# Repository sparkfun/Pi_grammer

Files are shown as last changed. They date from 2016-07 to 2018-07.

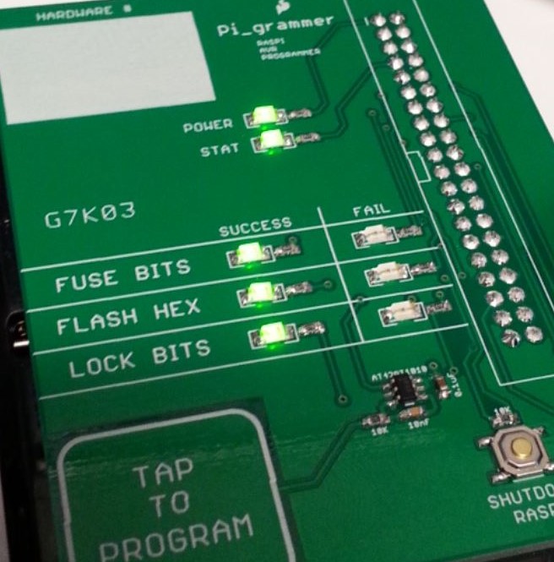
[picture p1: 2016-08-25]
Documentation_ example_&_pics/verify.jpg

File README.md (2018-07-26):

SparkFun Pi AVR Programmer HAT
========================================

SparkFun Raspberry Pi Stand-Alone Programmer w/ the Pi-Grammer Hat

[*SparkFun Pi AVR Programmer HAT (DEV-14747)*](https://www.sparkfun.com/products/14747)

A shield for Raspberry Pi 2, used for programming AVR ICs. Includes capsense pad to engage, 2x3 ISP header for connectivity and status LEDs.

Documentation
--------------
* **[Hookup Guide](https://learn.sparkfun.com/tutorials/pi-avr-programmer-hat-hookup-guide)** - Basic hookup guide for the Pi AVR Programmer Hat.
* **[Raspberry Pi Stand-Alone Programmer](https://learn.sparkfun.com/tutorials/raspberry-pi-stand-alone-programmer)** - more information about the prototype can be found in the article.

Additional Notes
--------------
This project originated from Adafruits tutorial here:

https://learn.adafruit.com/program-an-avr-or-arduino-using-raspberry-pi-gpio-pins/overview

This shield makes it a bit easier to program AVRs with a headless Raspberry Pi.

This repo also contains some other useful files:

* **RCLOCAL** - calls /home/pi/test.py and ensure that this python module will run automatically at boot up (useful when running headless)

* **AVRDUDE config file** - sets the GPIO used for programming (in avrdude) to work with the shield design. It's located at the very end of this file.

* **test.py** - the python module that is auto called during bootup. This also listens to the capsense IC and engages programming when p ressed.

**Note:** test.py called pi_program.sh to actually begin programming.

**Note:** test.py also checks for MEDIA drives plugged into the USB ports of the Raspi. If there is a HEX file on the MEDIA drive (any name, it just has to have the ".hex" extension) it will copy it in and use that for programming.

KEYWORDS: RASPI PROGRAMMER

Troubleshooting Tips
--------------

1) USB port issues. If you are having trouble with com port enumeration. That is, you are plugging in something like an FTDI serial basic, and the Raspi will not recognize it. This may be fixed by using one of SparkFun Cerberus USB hub cables. We found that after plugging in 20+ FTDI basics into a pi, then it stops recognizing the devices. But if you use a hub (like the cerberus) inbetween the pi USB and the serial bridge IC, then it always pops up as "/dev/ttyUSB0" for 1000s of boards in a row. Wahoo!

SparkFun Cerberus USB Cable

[SparkFun Cerberus USB Cable](https://www.sparkfun.com/products/12016)

License Information
-------------------

This product is _**open source**_! 

Please review the LICENSE.md file for license information. 

If you have any questions or concerns on licensing, please contact techsupport@sparkfun.com.

Distributed as-is; no warranty is given.

- Your friends at SparkFun.

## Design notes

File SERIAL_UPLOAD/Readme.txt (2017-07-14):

Note, you must install arduino for the serial upload to work. The latest Pigrammer image should have this done already, but if needed, here is the command:

sudo apt-get install arduino

////////////////
Note, you will need to plug in an ethernet cable to your pi 2, to connect to the internet. I found that I needed to open a browser a couple times for it to actually connect to the internet (which you need for the apt-get to work).

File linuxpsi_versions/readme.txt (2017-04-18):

Note, you must follow some setup instructions on an SFE tutorial to get SPI setup correctly. 

You can find that here:

https://learn.sparkfun.com/tutorials/raspberry-pi-spi-and-i2c-tutorial#spi-on-pi

SPI on Pi
Configuration

The SPI peripheral is not turned on by default. To enable it, do the following.

Run sudo raspi-config.
Use the down arrow to select 9 Advanced Options
Arrow down to A6 SPI.
Select yes when it asks you to enable SPI,
Also select yes when it asks about automatically loading the kernel module.
Use the right arrow to select the <Finish> button.
Select yes when it asks to reboot.

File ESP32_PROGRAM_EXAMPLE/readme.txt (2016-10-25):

Note, the espressif folder and all it's contents must live in the /home/pi folder for the pi_program.sh example to call the correct python moldule esptool.py

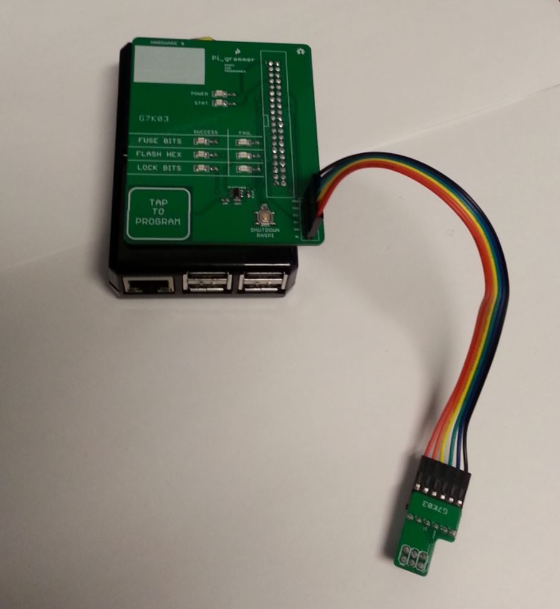
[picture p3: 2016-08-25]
Documentation_ example_&_pics/Pi_grammer_with_adapter.jpg

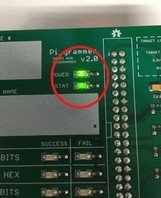
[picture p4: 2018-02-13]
Documentation_ example_&_pics/V20_pics/stat.jpg

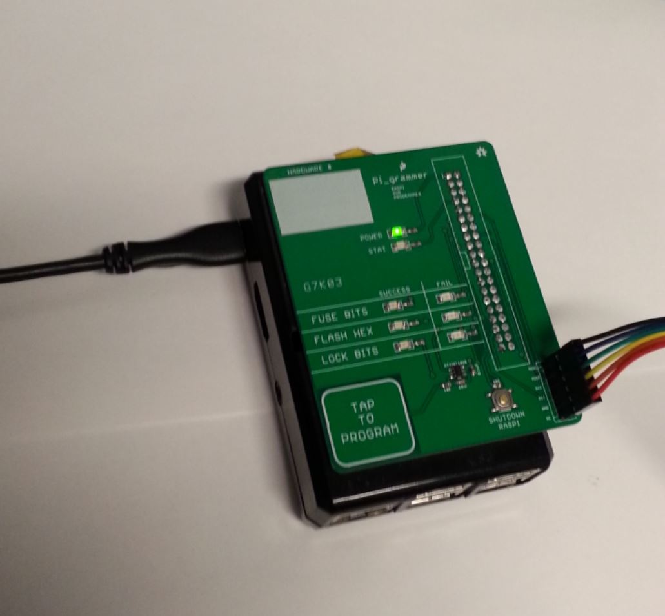
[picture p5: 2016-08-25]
Documentation_ example_&_pics/power.jpg

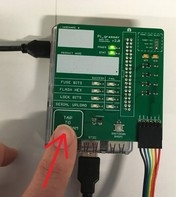
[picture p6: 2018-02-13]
Documentation_ example_&_pics/V20_pics/tap.jpg

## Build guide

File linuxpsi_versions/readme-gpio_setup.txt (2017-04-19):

Note, you will also need to insall the gpio control stuff for the hard reset to work.

Read more at tutorial here:

https://learn.sparkfun.com/tutorials/raspberry-gpio#c-wiringpi-setup

Or you can simply run these commands: (also note that you'll need to be connected to a hard line to the internet for this to pull the necessary git clone). And don't forget the darn "sudo" - oh how I loath permissions.

sudo mkdir code
sudo ch code

pi@raspberrypi ~/code $ sudo git clone git://git.drogon.net/wiringPi
pi@raspberrypi ~/code $ sudo cd wiringPi
pi@raspberrypi ~/code/wiringPi $ sudo git pull origin
pi@raspberrypi pi@raspberrypi ~/code/wiringPi/wiringPi $ sudo ./build

test gpio control like so:

pi@raspberrypi ~/code $ gpio -g mode 18 output
pi@raspberrypi ~/code $ gpio -g write 18 1
pi@raspberrypi ~/code $ gpio -g write 18 0

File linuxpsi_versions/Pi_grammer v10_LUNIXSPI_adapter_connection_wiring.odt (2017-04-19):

Pi_grammer v10

SPI adapter wiring instructions

Pete Lewis

4/19/2017

For use with “linuxspi” programmer in avrdude.

Note, I originally designed the Pi_grammer to use GPIO pins to “bitbang” SPI. This is slower than using the built in SPI hardware pins on the raspi. And is problematic when programming large hex files.

The Pi_grammer hardware should be revised to use the true SPI hardware pins (and include a logic level converter to allow for 5V targets), but for now, we can wire up our adapters and only use it on 3.3V boards.

Here are the SPI hardware pins:

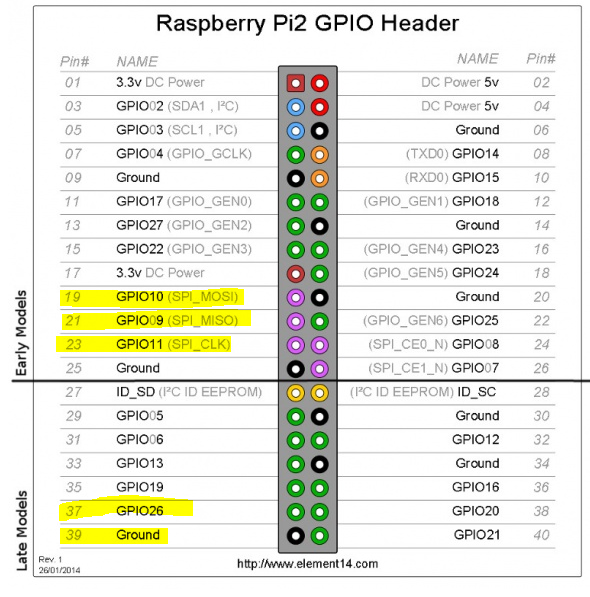
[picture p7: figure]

This is what it looks like on my soldered board. The MOSI/MISO/CLK actually line up nicely with the 1x6 adapter order.

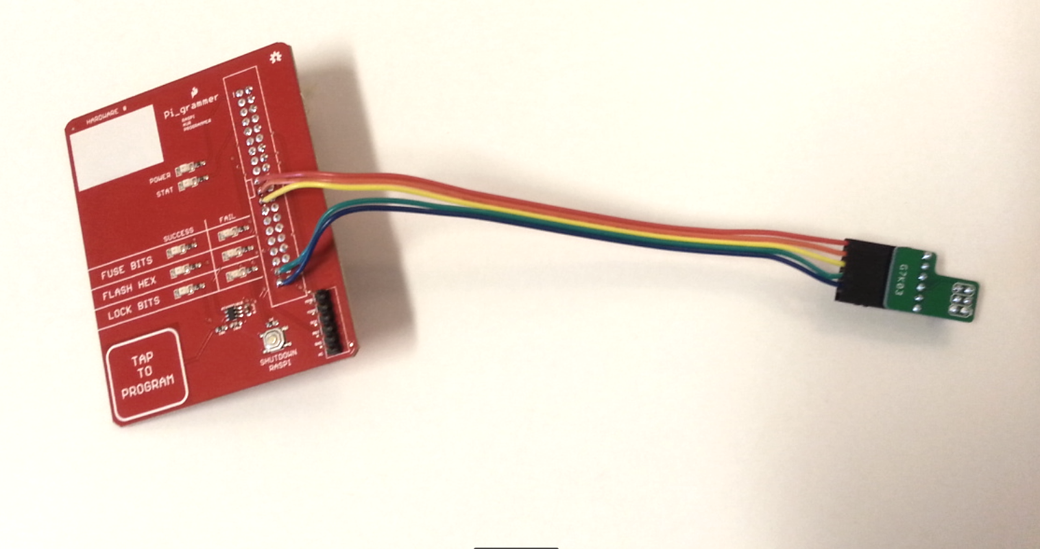
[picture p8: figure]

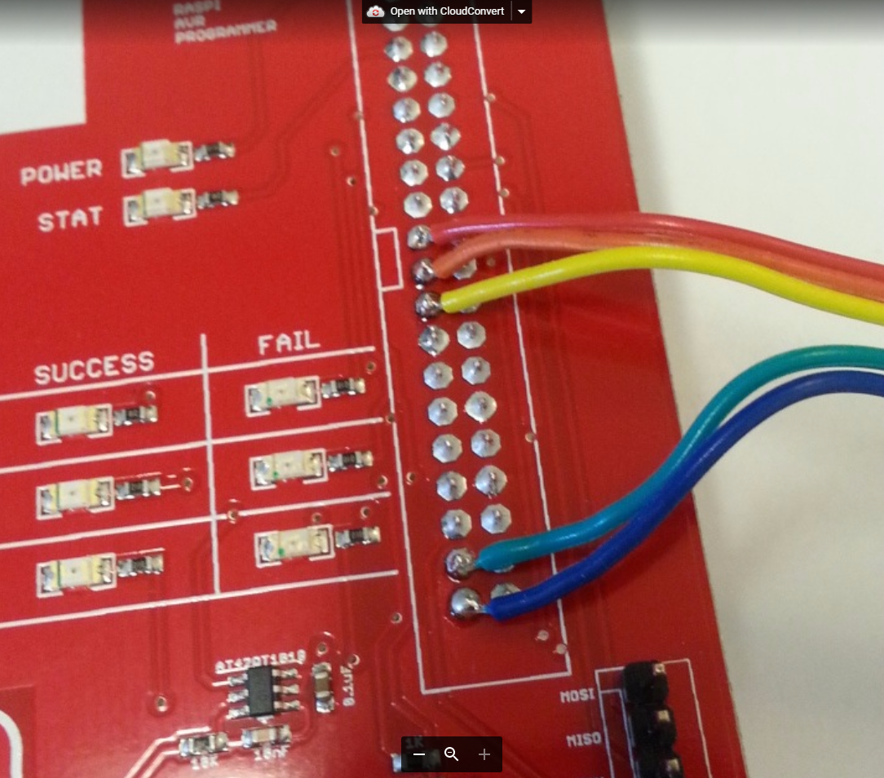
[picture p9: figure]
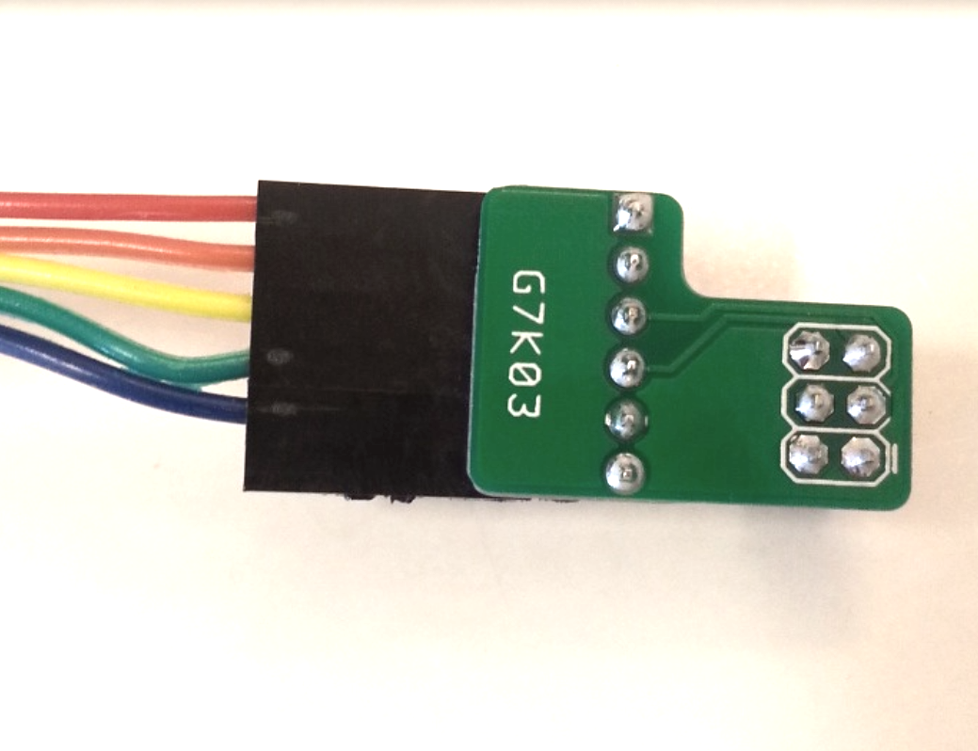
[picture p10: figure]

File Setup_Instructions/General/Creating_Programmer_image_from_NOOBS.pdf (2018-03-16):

Creating a Pi_grammer Image from NOOBs PL 3/16/2018

This guide will show how to take a fresh NOOBs card, and make some slight tweaks to get it setup as a Pi_grammer..

1. Copy a few files to “\home\pi” directory: test.py, pi_program.sh, avrdude_gpio.conf, your_firmware.hex.

Note, it’s a good idea to open up permissions on all of these files to avoid access errors in debug. To do this navigate to \home\pi, then type use the command “sudo chmod 777 test.py pi_program.sh your_firmware.hex”

Also note, the avrdude_gpio.conf file is pretty similar to the standard CONF file, although it has two additional programmers setup at the bottom of the file. This is added to the end:

# Linux GPIO configuration for avrdude.

# Change the lines below to the GPIO pins connected to the AVR.

programmer
id = "pi_1";
desc = "Use the Linux sysfs interface to bitbang GPIO lines"; type = "linuxgpio";
reset = 19;
sck = 24;
mosi = 23;
miso = 18;
;

programmer
id = "linuxspi";
desc = "Use the Linux SPI device in /dev/spidev*"; type = "linuxspi";
reset = 26;
;
2. Enable SPI hardware tutorial here: https://learn.sparkfun.com/tutorials/raspberry-pi-spi-and-i2c-tutorial#spi-on-pi
3. Replace the standard RC.LOCAL file with the one from the repo. It is located here: “\etc”

4. Install avrdude. A single command will do this: “sudo apt-get install avrdude” but you can read more about it here adafruits gpio tutorial (https://learn.adafruit.com/program-an-avr-or-arduino-using-raspberry-pi-gpio-pins/installation)
Note, there is no need to create the modified config file for gpio if you intend to use linuxspi.

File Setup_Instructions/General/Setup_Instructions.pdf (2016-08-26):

Pi_Grammer Setup Instructions PL 8/26/2016

This guide will show how to setup a Pi_Grammer for production.

1. Grab a Raspi 2, a micro SD card (with generic Pi_grammer image pre-programmed) Pi_grammer Shield, 1x6 cable and adapter.
2. Create a bash file with proper fuse/ext/lock bits.
- Note, this can be done on your “usual” computer to avoid having to setup the Pi with a screen/mouse/keyboard each setup.
- Please start with the example “pi_program.sh” file that lives in the repo.
- Most of the time, you should only need to adjust the fuse/ext/lock bits. These are variables at the top of the bash file, for ease of editing.

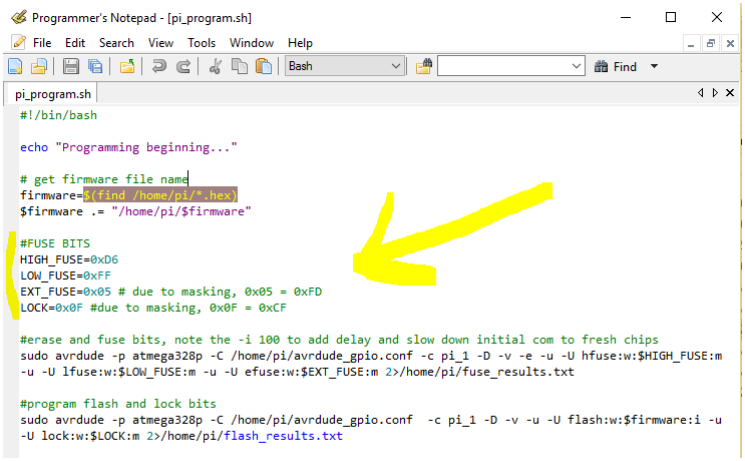
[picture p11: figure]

- Note, AVRDUDE will not let you write to “unused” bits. This effects how we write to the EXT and LOCK bits:
- If you want to write the value “0xFD” to the EXT bit (which is a common value we write on a lot of 328 based arduino products), then use the value “0x05” in AVRDUDE.

- The 3 bits on the right are the only ones we care about.
- “0xFD” = 1111 1101
- “0x05” = 0000 0101
- If you want to write the usual “0xCF” to LOCK, then write 0x0F” in AVRDUDE.
- The 4 bits on the right are the only ones we care about.
- “0xCF” = 1100 1111
- “0x0F” = 0000 1111
3. Go get the hex file from the product folder.
4. Copy the hex file and bash file onto your thumb drive.

Note, the hex file can be named anything (and so should be left the same as it was – for traceability). The bash file must be named exactly “pi_program.sh”. These should be the only two files on the thumb drive.

5. Plug in the uSD card (with generic image) into your Pi.
6. Power up your Pi with a microB USB cable (either a computer hub or wall wort).
7. Wait for blinking stat LED. This indicates that bootup is complete and the python script is running.
8. Take your prepared thumb drive (with hex and bash files) from your windows machine, and plug in your thumb drive into USB on the Pi.
9. Verify the circular LED sequence happens twice.
- One for hex file.
- Second for bash file.

- This verifies that the python script recognized the “media” device, found a “.hex” and a “pi_program.sh” file on it., and copied it to the local folder successfully.

10.Remove thumb drive.
11. Shutdown the Pi.
- Press and hold the “SHUTDOWN” button.
- All LEDs begin blinking.
- When blinking stops, that means it has fully shut down.
- Unplug power.

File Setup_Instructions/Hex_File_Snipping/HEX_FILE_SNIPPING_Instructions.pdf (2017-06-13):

HEX File Snipping Instructions PL 6/13/2017

Summary:
This guide will show how to remove unnecessary “blank” space in a hex file. This is useful when you want to keep the hex file as small as possible.

Why would you need this:
When a product has a bootloader and some “sketch code”, we will read back the entire flash space and use this as our “combined” HEX file for programming in production. Often times, this also includes a lot of blank space in the HEX file (between the sketch code and the bootloader).
1. Read the entire flash space of your IC. ATMEGA328s should come in at 91KB.
2. Open HEX file in a text editor. Here, I use Programmer Notepad.
3. Scroll up and down in the HEX file and notice the three sections:

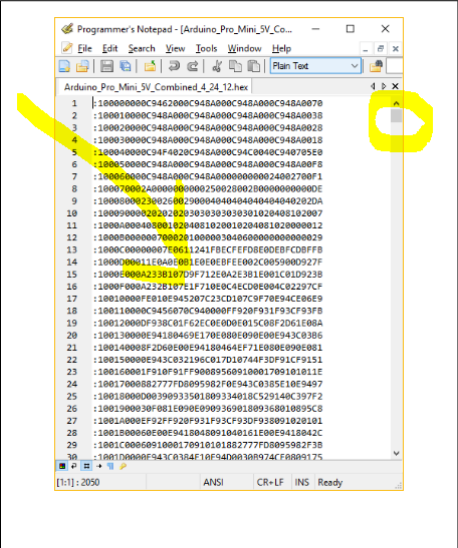
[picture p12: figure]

I. “good stuff” up top. (Sketch code).

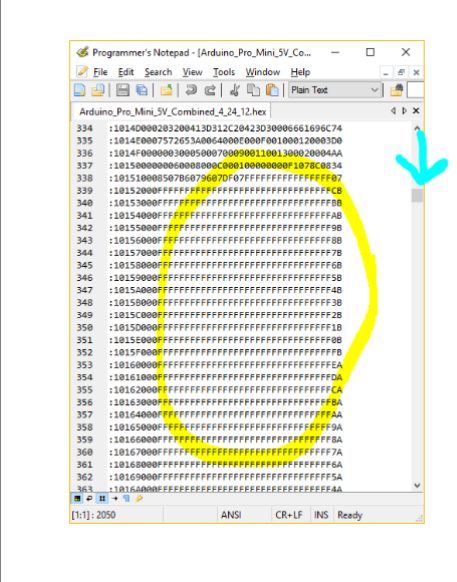
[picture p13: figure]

II. Blank writes in the middle. (all “FFFFFFFFFFF….”)

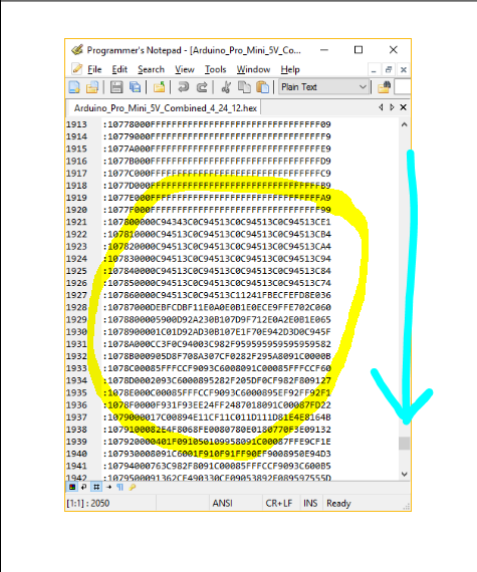
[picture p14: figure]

III. “good stuff at bottom. (bootloader).

4. Delete the blank writes in the file.

Do not accidentally delete any of the good stuff. To avoid this, I leave one line of complete “FFFFFFFFF” after the sketch code and before the bootloader.

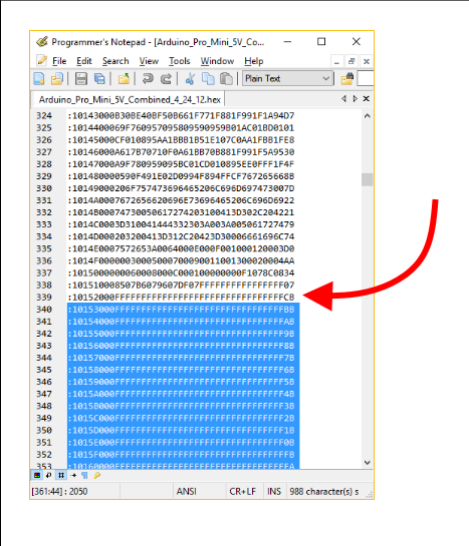
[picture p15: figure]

Buffer above selection.

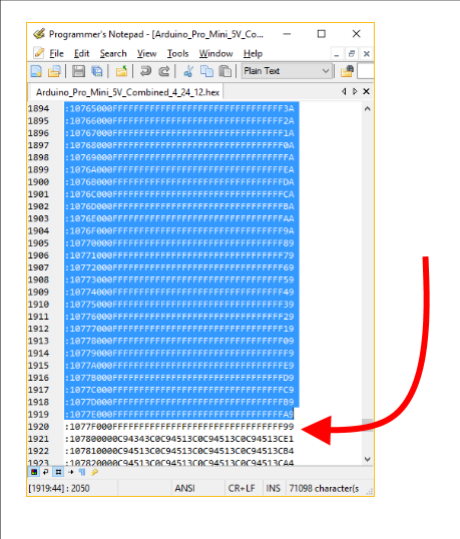
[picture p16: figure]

Buffer below selection.

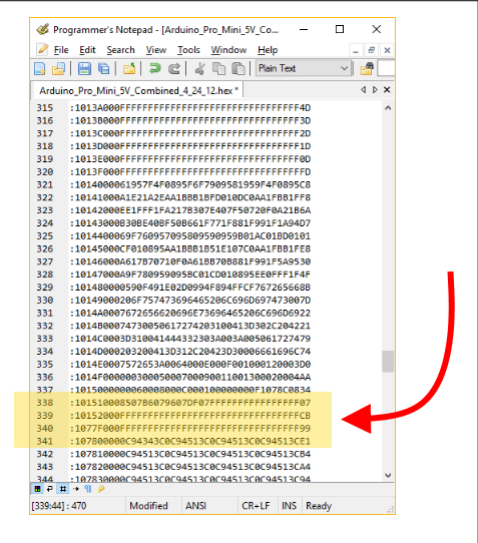
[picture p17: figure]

What it looks like after deletion.

5. Save new version for programming. Hell yeah! We just dropped this file size from 91KB to 21KB.
6. Verify your work. To do this properly, please follow these steps carefully and in order:
I. Erase chip.
II. Program new snipped HEX file.
III. Verify against the original (aka complete) combined HEX.
IV. If it verifies properly, then you are good to go. Rock on.

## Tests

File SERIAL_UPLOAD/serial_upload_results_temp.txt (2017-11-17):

avrdude: Version 6.1, compiled on Jul  7 2015 at 10:29:47
         Copyright (c) 2000-2005 Brian Dean, http://www.bdmicro.com/
         Copyright (c) 2007-2014 Joerg Wunsch

         System wide configuration file is "/usr/share/arduino/hardware/tools/avrdude.conf"
         User configuration file is "/root/.avrduderc"
         User configuration file does not exist or is not a regular file, skipping

         Using Port                    : /dev/ttyUSB0
         Using Programmer              : wiring
         Overriding Baud Rate          : 115200
         AVR Part                      : ATmega2560
         Chip Erase delay              : 9000 us
         PAGEL                         : PD7
         BS2                           : PA0
         RESET disposition             : dedicated
         RETRY pulse                   : SCK
         serial program mode           : yes
         parallel program mode         : yes
         Timeout                       : 200
         StabDelay                     : 100
         CmdexeDelay                   : 25
         SyncLoops                     : 32
         ByteDelay                     : 0
         PollIndex                     : 3
         PollValue                     : 0x53
         Memory Detail                 :

                                  Block Poll               Page                       Polled
           Memory Type Mode Delay Size  Indx Paged  Size   Size #Pages MinW  MaxW   ReadBack
           ----------- ---- ----- ----- ---- ------ ------ ---- ------ ----- ----- ---------
           eeprom        65    10     8    0 no       4096    8      0  9000  9000 0x00 0x00
           flash         65    10   256    0 yes    262144  256   1024  4500  4500 0x00 0x00
           lfuse          0     0     0    0 no          1    0      0  9000  9000 0x00 0x00
           hfuse          0     0     0    0 no          1    0      0  9000  9000 0x00 0x00
           efuse          0     0     0    0 no          1    0      0  9000  9000 0x00 0x00
           lock           0     0     0    0 no          1    0      0  9000  9000 0x00 0x00
           calibration    0     0     0    0 no          1    0      0     0     0 0x00 0x00
           signature      0     0     0    0 no          3    0      0     0     0 0x00 0x00

         Programmer Type : Wiring
         Description     : Wiring
         Programmer Model: AVRISP
         Hardware Version: 15
         Firmware Version Master : 2.10
         Vtarget         : 0.0 V
         SCK period      : 0.1 us

avrdude: AVR device initialized and ready to accept instructions

Reading | ################################################## | 100% 0.01s

avrdude: Device signature = 0x1e9801
avrdude: safemode: lfuse reads as 0
avrdude: safemode: hfuse reads as 0
avrdude: safemode: efuse reads as 0
avrdude: reading input file "/home/pi/SERIAL_UPLOAD/Flying_Jalapeno_selftest_v01.ino.mega.hex"
avrdude: writing flash (8780 bytes):

Writing | #

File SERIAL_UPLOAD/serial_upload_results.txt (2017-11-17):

avrdude: Version 6.1, compiled on Jul  7 2015 at 10:29:47
         Copyright (c) 2000-2005 Brian Dean, http://www.bdmicro.com/
         Copyright (c) 2007-2014 Joerg Wunsch

         System wide configuration file is "/usr/share/arduino/hardware/tools/avrdude.conf"
         User configuration file is "/root/.avrduderc"
         User configuration file does not exist or is not a regular file, skipping

         Using Port                    : /dev/ttyUSB0
         Using Programmer              : wiring
         Overriding Baud Rate          : 115200
         AVR Part                      : ATmega2560
         Chip Erase delay              : 9000 us
         PAGEL                         : PD7
         BS2                           : PA0
         RESET disposition             : dedicated
         RETRY pulse                   : SCK
         serial program mode           : yes
         parallel program mode         : yes
         Timeout                       : 200
         StabDelay                     : 100
         CmdexeDelay                   : 25
         SyncLoops                     : 32
         ByteDelay                     : 0
         PollIndex                     : 3
         PollValue                     : 0x53
         Memory Detail                 :

                                  Block Poll               Page                       Polled
           Memory Type Mode Delay Size  Indx Paged  Size   Size #Pages MinW  MaxW   ReadBack
           ----------- ---- ----- ----- ---- ------ ------ ---- ------ ----- ----- ---------
           eeprom        65    10     8    0 no       4096    8      0  9000  9000 0x00 0x00
           flash         65    10   256    0 yes    262144  256   1024  4500  4500 0x00 0x00
           lfuse          0     0     0    0 no          1    0      0  9000  9000 0x00 0x00
           hfuse          0     0     0    0 no          1    0      0  9000  9000 0x00 0x00
           efuse          0     0     0    0 no          1    0      0  9000  9000 0x00 0x00
           lock           0     0     0    0 no          1    0      0  9000  9000 0x00 0x00
           calibration    0     0     0    0 no          1    0      0     0     0 0x00 0x00
           signature      0     0     0    0 no          3    0      0     0     0 0x00 0x00

         Programmer Type : Wiring
         Description     : Wiring
         Programmer Model: AVRISP
         Hardware Version: 15
         Firmware Version Master : 2.10
         Vtarget         : 0.0 V
         SCK period      : 0.1 us

avrdude: AVR device initialized and ready to accept instructions

Reading | ################################################## | 100% 0.01s

avrdude: Device signature = 0x1e9801
avrdude: safemode: lfuse reads as 0
avrdude: safemode: hfuse reads as 0
avrdude: safemode: efuse reads as 0
avrdude: reading input file "/home/pi/SERIAL_UPLOAD/Flying_Jalapeno_selftest_v01.ino.mega.hex"
avrdude: writing flash (8780 bytes):

Writing | ################################################## | 100% 1.29s

avrdude: 8780 bytes of flash written
avrdude: verifying flash memory against /home/pi/SERIAL_UPLOAD/Flying_Jalapeno_selftest_v01.ino.mega.hex:
avrdude: load data flash data from input file /home/pi/SERIAL_UPLOAD/Flying_Jalapeno_selftest_v01.ino.mega.hex:
avrdude: input file /home/pi/SERIAL_UPLOAD/Flying_Jalapeno_selftest_v01.ino.mega.hex contains 8780 bytes
avrdude: reading on-chip flash data:

Reading | ################################################## | 100% 0.99s

avrdude: verifying ...
avrdude: 8780 bytes of flash verified

avrdude: safemode: lfuse reads as 0
avrdude: safemode: hfuse reads as 0
avrdude: safemode: efuse reads as 0
avrdude: safemode: Fuses OK (E:00, H:00, L:00)

avrdude done.  Thank you.

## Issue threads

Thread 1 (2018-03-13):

SPI_ISOLATE add-on board needs logic level conversion on CTRL line

lewispg228, 2018-03-13:
I just tested this out, and when using a 5V target, the CRTL line will be tied to 5V. If you want to control this with a GPIO off of the pi, then we will need to add logic level conversion from 3.3V to logic level of the MUX IC.

A work around I just tried out: I added a 10K pull down resistor to CRTL, so that it sits at 1/2 of VCC. In my use case, this puts it at 2.5V. It still effectively enables/disables the MUX, and I can use a GPIO off the pi (36 for me), to control the switch.

If this MUX ever gets baked into the MAIN (aka "HAT"), It' be better to put proper logic conversion between the GPIO and the CTRL line.

lewispg228, 2018-04-02:
I revised the MAIN board to include the iso switch. It also converts the logic level of the pi GPIO to the target logic level.

https://github.com/sparkfun/Pi_grammer/commit/7796cda8295a7a3567e9050fca7463d59af50d91

Closed 2018-04-02.

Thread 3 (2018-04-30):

v22 checklist issues

ericorosel, 2018-04-30:
(1) power LED has a flag type label for 3.3V not a vcc symbol

lewispg228, 2018-04-30:
Thanks @ericorosel Fixed. Here's the commit for reference:

https://github.com/sparkfun/Pi_grammer/commit/aa21ff8c69d69e8b8320f6d32c1ccfd2b25f5d3c

Closed 2018-04-30.

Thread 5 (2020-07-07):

Python3 Support

sako0938, 2020-07-07:
Since Python2 is EOL, it would be good to start moving to Python.

sako0938, 2020-07-10:
I have a working python3 version. I am thinking about switching the gpio library to the gpiozero library, as wiringpi seems to be deprecated. Will make a PR soon

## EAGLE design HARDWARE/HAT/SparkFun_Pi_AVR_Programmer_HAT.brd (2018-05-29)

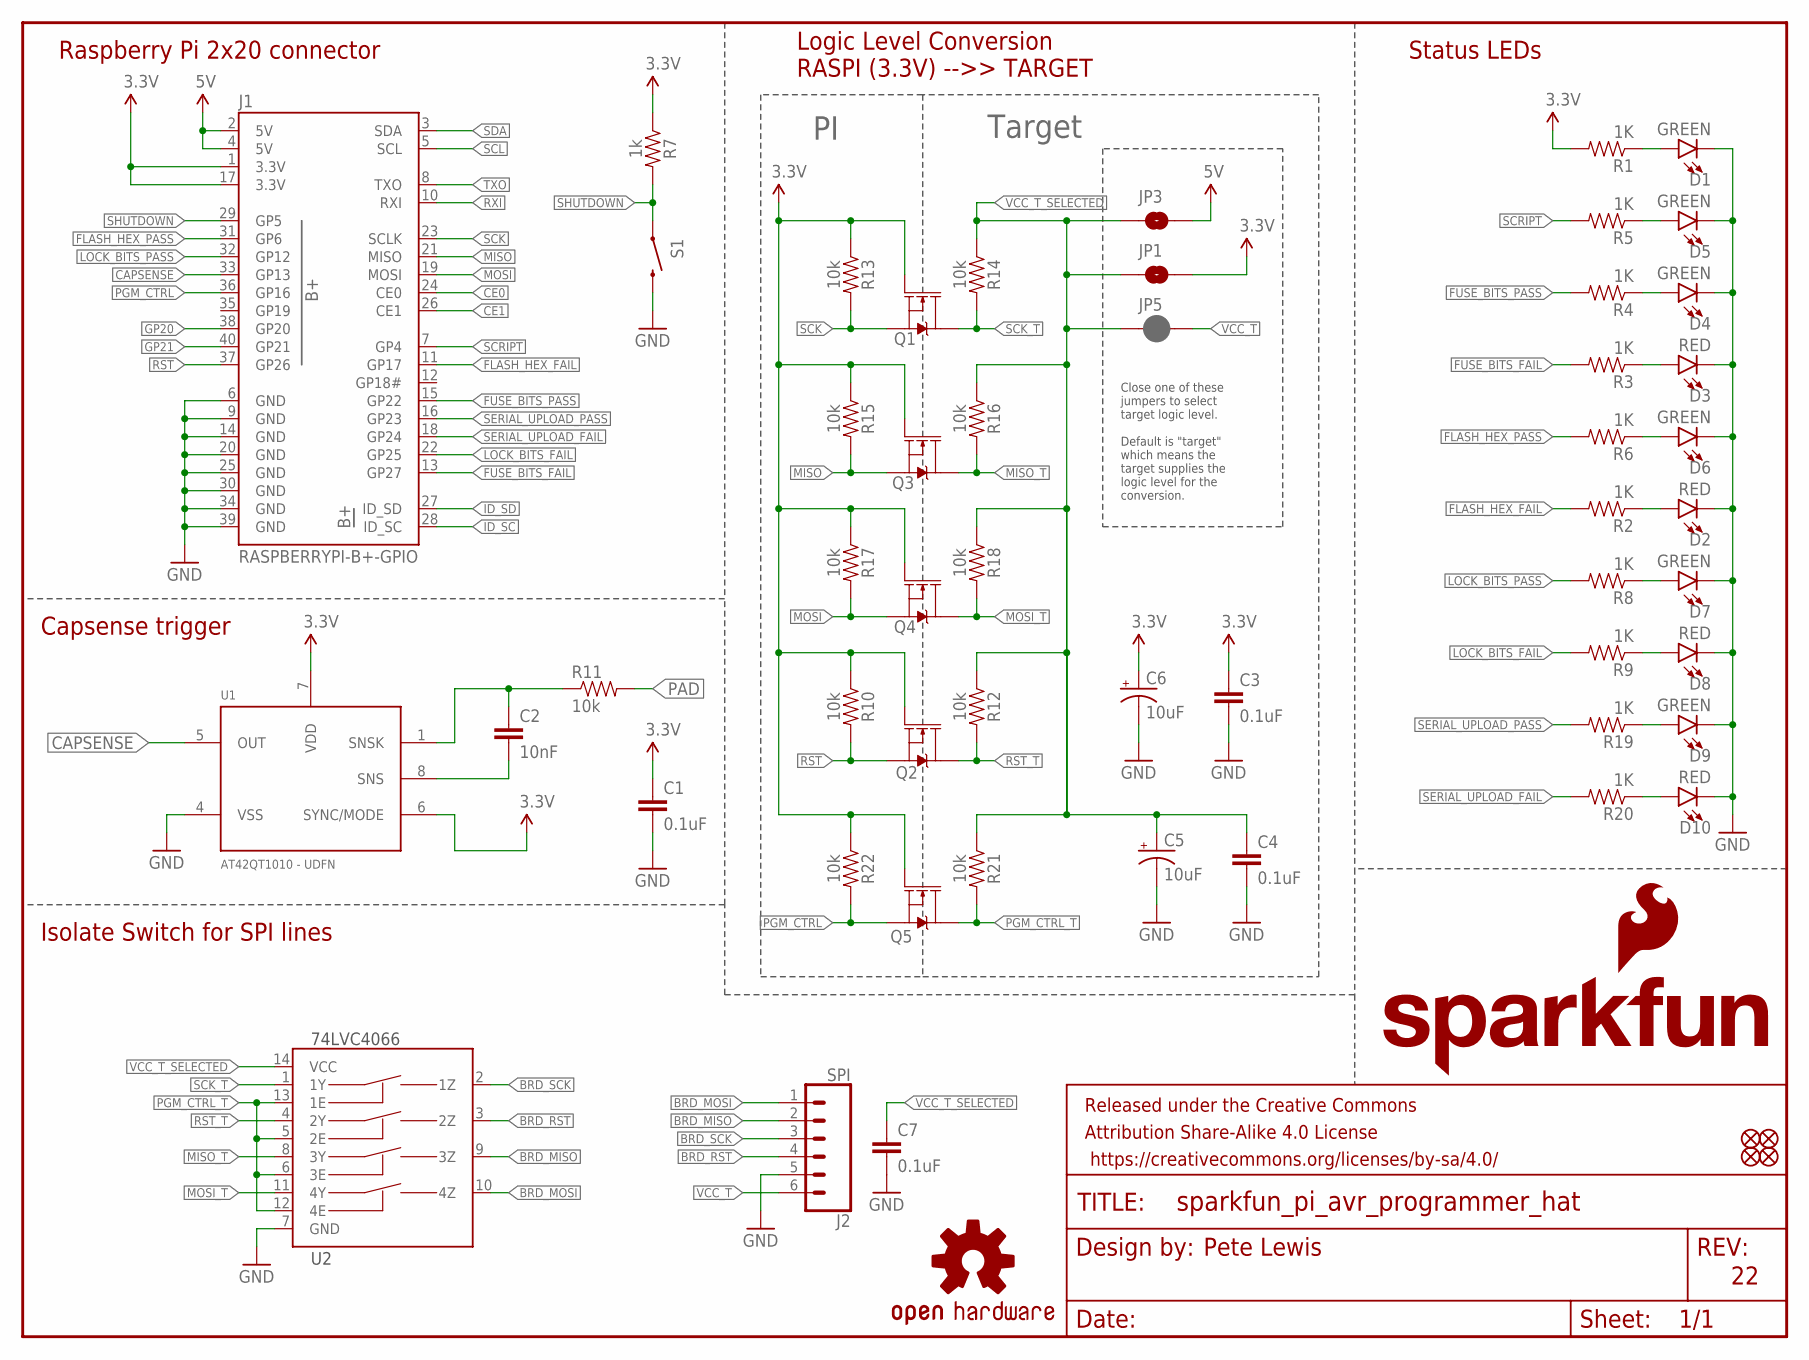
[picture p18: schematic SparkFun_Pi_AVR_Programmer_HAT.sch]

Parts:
C1: 0.1uF; 0603-CAP
C2: 10nF; 0603-CAP
C3, C4, C7: 0.1uF; 0603
C5, C6: 10uF; EIA3216
D1, D4, D5, D6, D7, D9: GREEN; LED-1206
D2, D3, D8, D10: RED; LED-1206
FD1, FD2, FD3, FD4: FIDUCIALUFIDUCIAL; FIDUCIAL-MICRO
FRAME1: FRAME-LETTER; CREATIVE_COMMONS
J1: RASPBERRYPI-B+-GPIO; 2X20-SHROUDED
J2: SPI; 1X06-SMD_RA_MALE
JP1, JP3: JUMPER-SMT_2_NO_SILK; SMT-JUMPER_2_NO_SILK
JP5: JUMPER-SMT_2_NC_PASTE_SILK; SMT-JUMPER_2_NC_PASTE_SILK
LOGO1: SFE_LOGO_FLAME.2_INCH; SFE_LOGO_FLAME_.2
LOGO2: OSHW-LOGOL; OSHW-LOGO-L
LOGO3: SFE_LOGO_NAME.6_INCH; SFE_LOGO_NAME_.6
Q1, Q2, Q3, Q4, Q5: 220mA/50V/3.5Ω; SOT23-3
R1, R2, R3, R4, R5, R6, R8, R9, R19, R20: 1K; 0603-RES
R7: 1k; 0603
R10, R12, R13, R14, R15, R16, R17, R18, R21, R22: 10k; 0603
R11: 10k; 0603-RES
S1: SWITCH-MOMENTARY-2SMD; TACTILE-SWITCH-SMD
U1: AT42QT1010 - UDFN; UDFN/USON_8_PAD
U2: 74LVC4066; SO14

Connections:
3.3V: C1.1, C3.1, C6.+, J1.1 (3.3V), J1.17 (3.3V), JP1.2, Q1.1 (G), Q2.1 (G), Q3.1 (G), Q4.1 (G), Q5.1 (G), R1.2, R7.1, R10.1, R13.1, R15.1, R17.1, R22.1, U1.6 (SYNC/MODE), U1.7 (VDD)
5V: J1.2 (5V), J1.4 (5V), JP3.2
BRD_MISO: J2.2, U2.9 (3Z)
BRD_MOSI: J2.1, U2.10 (4Z)
BRD_RST: J2.4, U2.3 (2Z)
BRD_SCK: J2.3, U2.2 (1Z)
CAPSENSE: J1.33 (GP13), U1.5 (OUT)
CE0: J1.24 (CE0)
CE1: J1.26 (CE1)
FLASH_HEX_FAIL: J1.11 (GP17), R2.2
FLASH_HEX_PASS: J1.31 (GP6), R6.2
FUSE_BITS_FAIL: J1.13 (GP27), R3.2
FUSE_BITS_PASS: J1.15 (GP22), R4.2
GND: C1.2, C3.2, C4.2, C5.-, C6.-, C7.2, D1.C, D2.C, D3.C, D4.C, D5.C, D6.C, D7.C, D8.C, D9.C, D10.C, J1.6 (GND), J1.9 (GND), J1.14 (GND), J1.20 (GND), J1.25 (GND), J1.30 (GND), J1.34 (GND), J1.39 (GND), J2.5, S1.3 (2), U1.4 (VSS), U2.7 (GND)
GP20: J1.38 (GP20)
GP21: J1.40 (GP21)
ID_SC: J1.28 (ID_SC)
ID_SD: J1.27 (ID_SD)
LOCK_BITS_FAIL: J1.22 (GP25), R9.2
LOCK_BITS_PASS: J1.32 (GP12), R8.2
MISO: J1.21 (MISO), Q3.2 (S), R15.2
MISO_T: Q3.3 (D), R16.2, U2.8 (3Y)
MOSI: J1.19 (MOSI), Q4.2 (S), R17.2
MOSI_T: Q4.3 (D), R18.2, U2.11 (4Y)
unnamed: D6.A, R6.1
unnamed: D1.A, R1.1
unnamed: D2.A, R2.1
unnamed: D3.A, R3.1
unnamed: D7.A, R8.1
unnamed: D4.A, R4.1
unnamed: D5.A, R5.1
unnamed: D8.A, R9.1
unnamed: C2.2, U1.8 (SNS)
unnamed: C2.1, R11.1, U1.1 (SNSK)
unnamed: D9.A, R19.1
unnamed: D10.A, R20.1
PAD: R11.2
PGM_CTRL: J1.36 (GP16), Q5.2 (S), R22.2
PGM_CTRL_T: Q5.3 (D), R21.2, U2.5 (2E), U2.6 (3E), U2.12 (4E), U2.13 (1E)
RST: J1.37 (GP26), Q2.2 (S), R10.2
RST_T: Q2.3 (D), R12.2, U2.4 (2Y)
RXI: J1.10 (RXI)
SCK: J1.23 (SCLK), Q1.2 (S), R13.2
SCK_T: Q1.3 (D), R14.2, U2.1 (1Y)
SCL: J1.5 (SCL)
SCRIPT: J1.7 (GP4), R5.2
SDA: J1.3 (SDA)
SERIAL_UPLOAD_FAIL: J1.18 (GP24), R20.2
SERIAL_UPLOAD_PASS: J1.16 (GP23), R19.2
SHUTDOWN: J1.29 (GP5), R7.2, S1.1
TXO: J1.8 (TXO)
VCC_T: J2.6, JP5.2
VCC_T_SELECTED: C4.1, C5.+, C7.1, JP1.1, JP3.1, JP5.1, R12.1, R14.1, R16.1, R18.1, R21.1, U2.14 (VCC)

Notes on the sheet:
Raspberry Pi 2x20 connector
Pete Lewis
Status LEDs
Capsense trigger
Target
Logic Level Conversion RASPI (3.3V) -->> TARGET
Isolate Switch for SPI lines
Close one of these jumpers to select target logic level. Default is "target" which means the target supplies the logic level for the conversion.

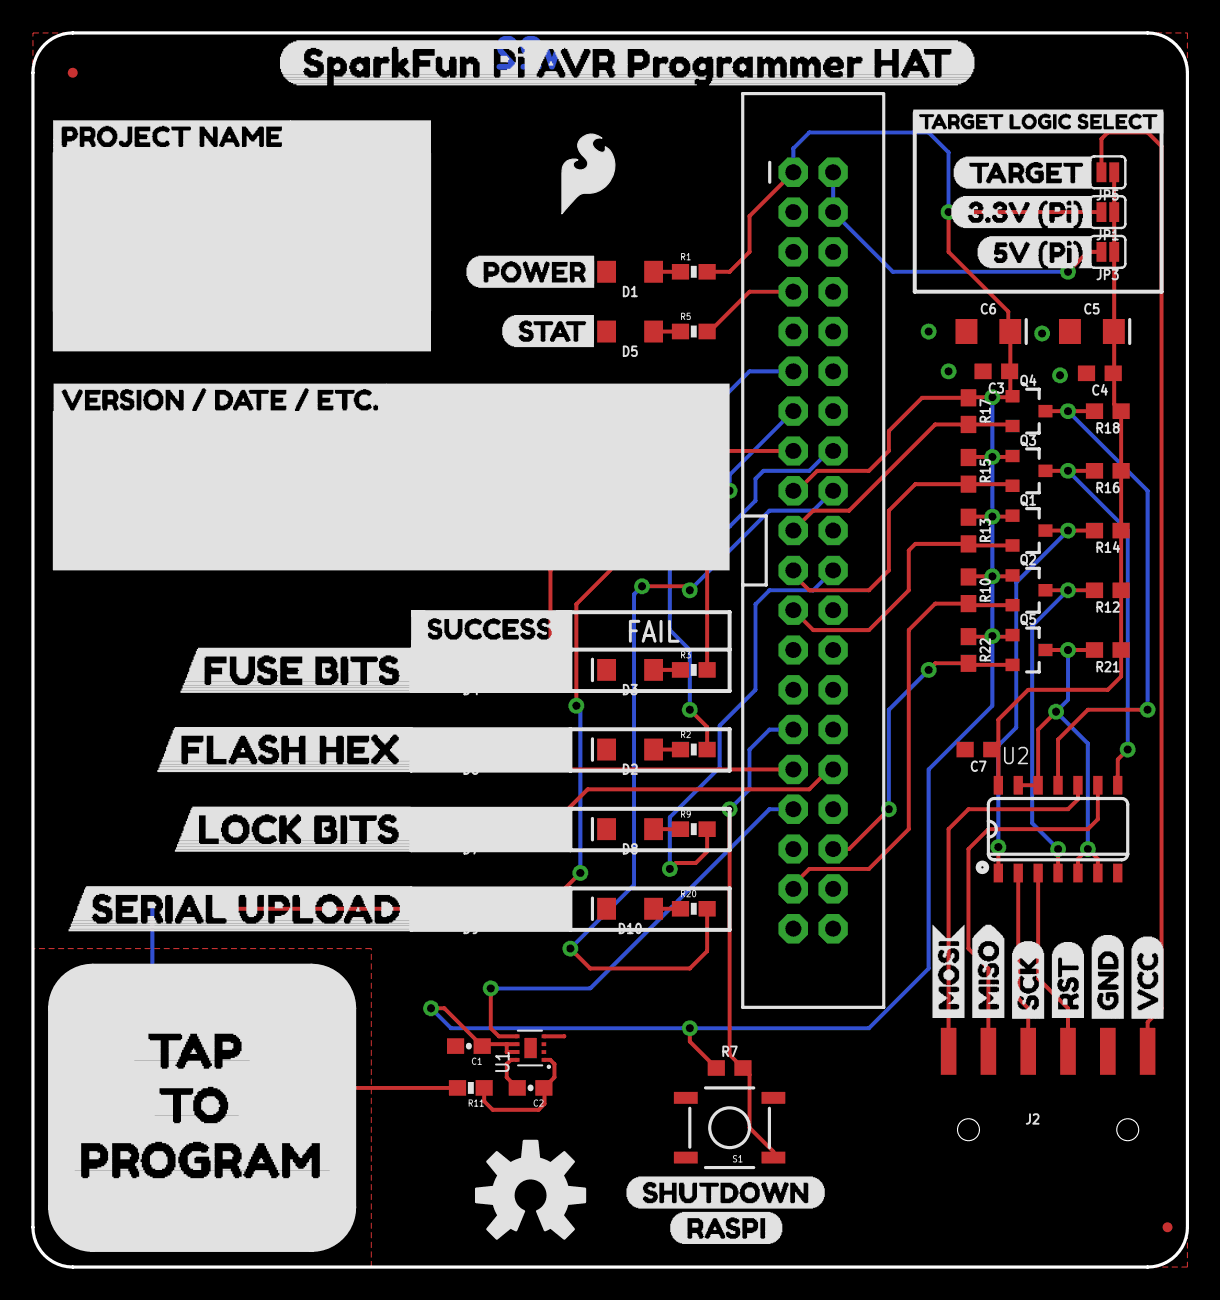
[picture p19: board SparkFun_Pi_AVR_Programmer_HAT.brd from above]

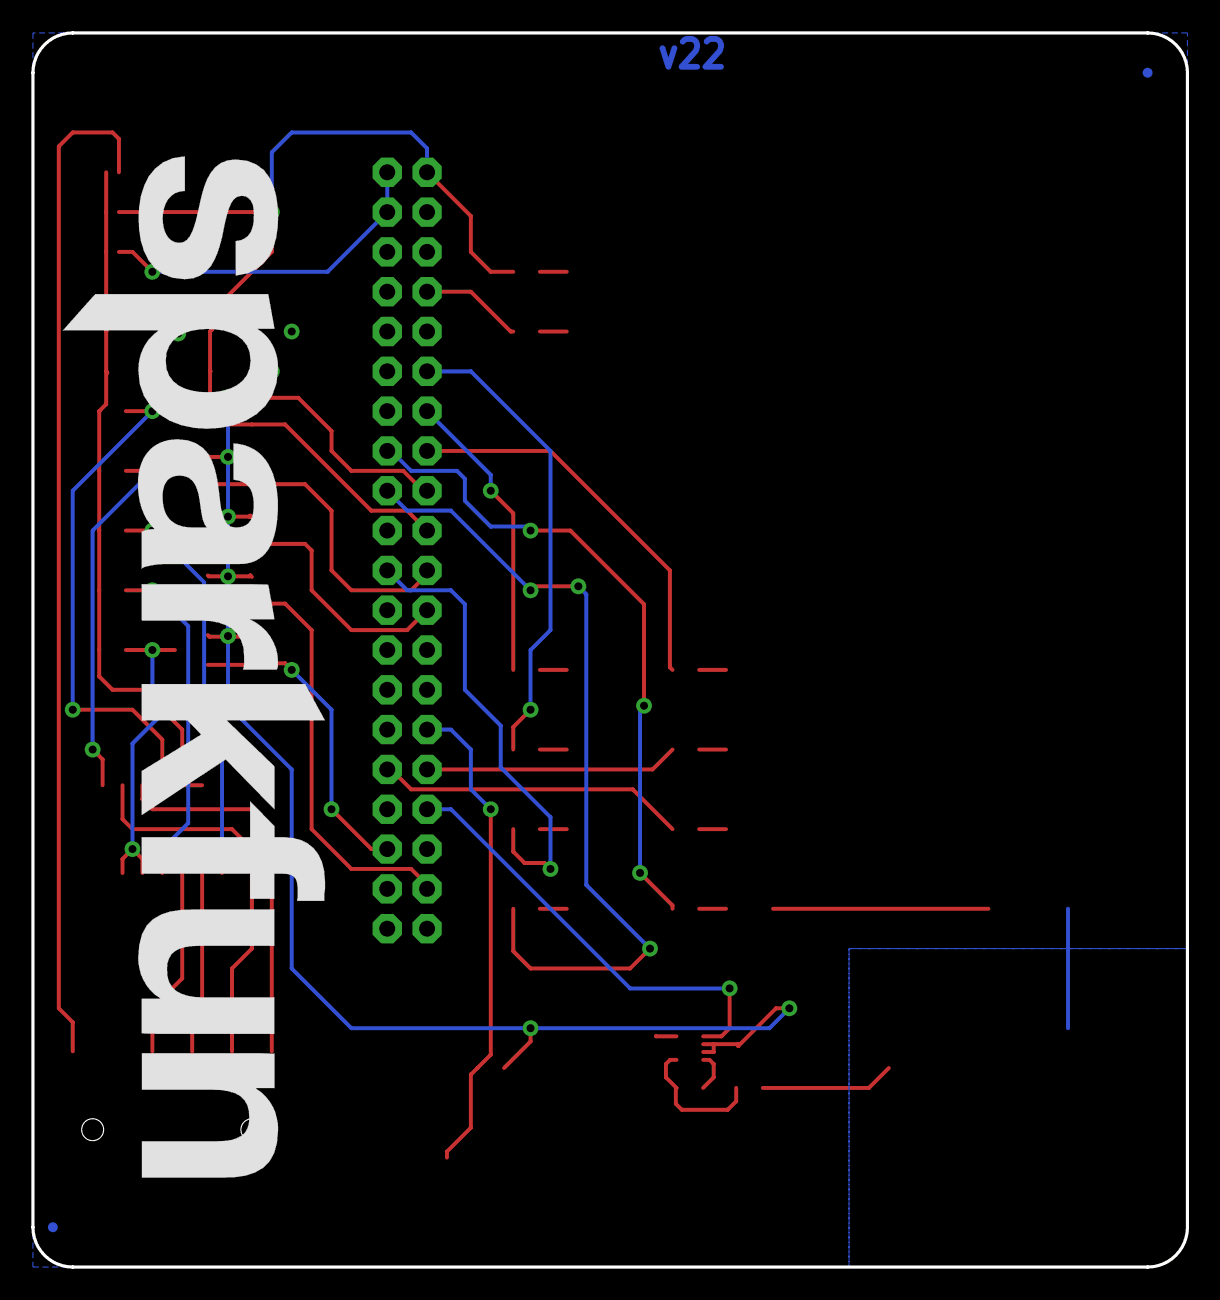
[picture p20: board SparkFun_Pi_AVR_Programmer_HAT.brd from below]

Board: 2 copper layers, 73.7 x 78.7 mm, 85 parts (3 on the bottom side), 42 nets.

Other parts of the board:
U$1: SPARKFUN_PI_AVR_PROGRAMMER_HAT0
U$2: PROJECT_NAME0
U$3: VERSION_#_DATE_#_ETC#0
U$4: TARGET_LOGIC_SELECT4
U$5: POWER0
U$6: STAT1
U$7: SHUTDOWN2
U$8: RASPI3
U$9: 3#3V_#PI#7
U$10: 5V_#PI#8
U$11: TARGET0
U$12: MISO1
U$13: MOSI0
U$14: SCK2
U$15: RST3
U$16: GND4
U$18: TAP0
U$19: TO1
U$20: PROGRAM2
U$21: VCC0
U$22: SUCCESS0
U$23: FUSE_BITS2
U$24: FLASH_HEX3
U$25: LOCK_BITS4
U$26: SERIAL_UPLOAD5

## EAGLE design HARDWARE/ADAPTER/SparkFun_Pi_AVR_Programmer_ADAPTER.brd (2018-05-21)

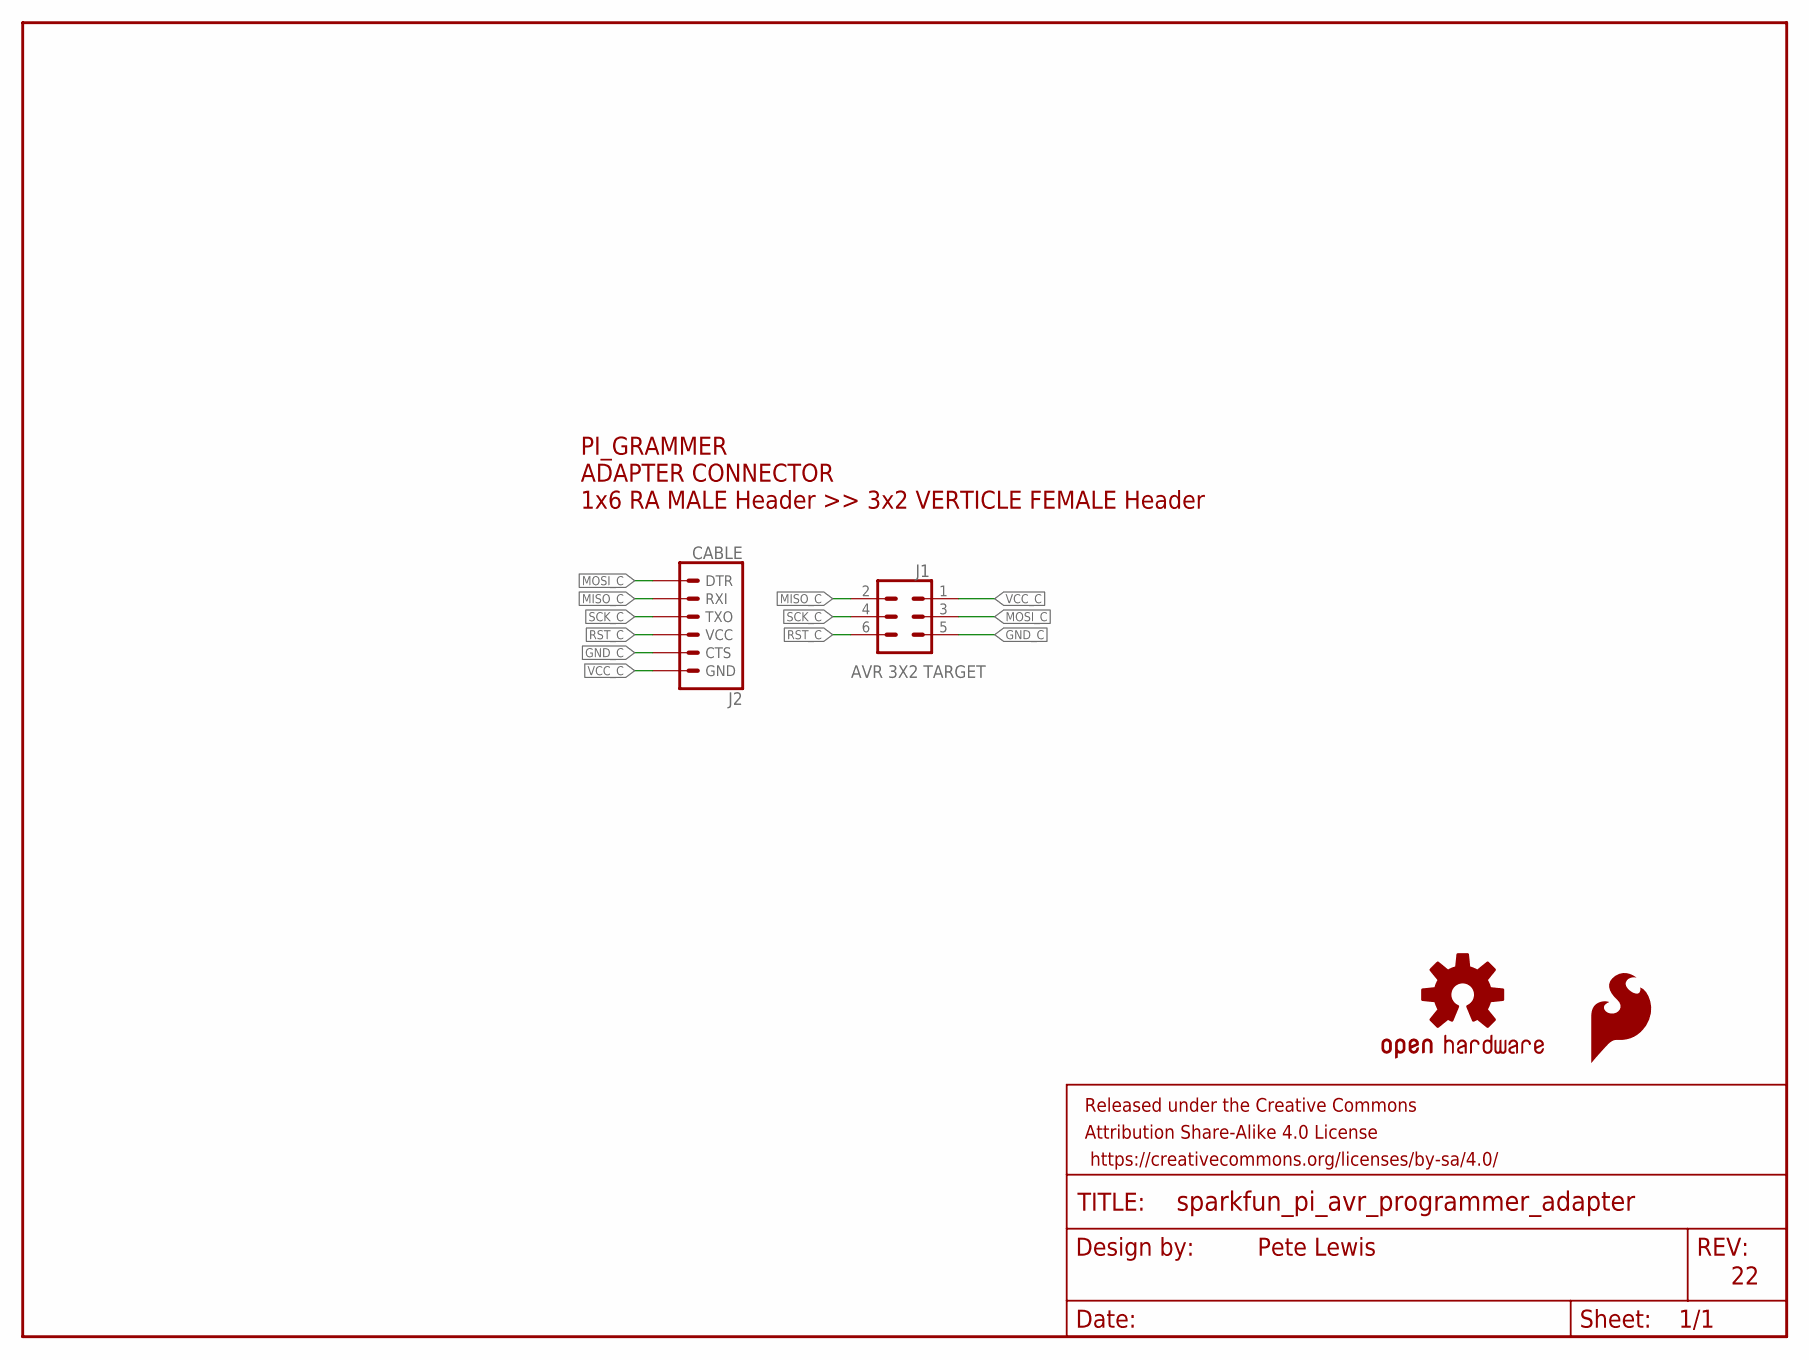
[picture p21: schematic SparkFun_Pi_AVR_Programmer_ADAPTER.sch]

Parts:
FRAME1: FRAME-LETTER; CREATIVE_COMMONS
J1: AVR 3X2 TARGET; 2X3_SMT_POSTS
J2: CABLE; 1X06-SMD_RA_MALE
LOGO1: SFE_LOGO_FLAME.1_INCH; SFE_LOGO_FLAME_.1
LOGO2: OSHW-LOGOMINI; OSHW-LOGO-MINI

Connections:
GND_C: J1.5, J2.5 (CTS)
MISO_C: J1.2, J2.2 (RXI)
MOSI_C: J1.3, J2.1 (DTR)
RST_C: J1.6, J2.4 (VCC)
SCK_C: J1.4, J2.3 (TXO)
VCC_C: J1.1, J2.6 (GND)

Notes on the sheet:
PI_GRAMMER ADAPTER CONNECTOR 1x6 RA MALE Header >> 3x2 VERTICLE FEMALE Header
Pete Lewis

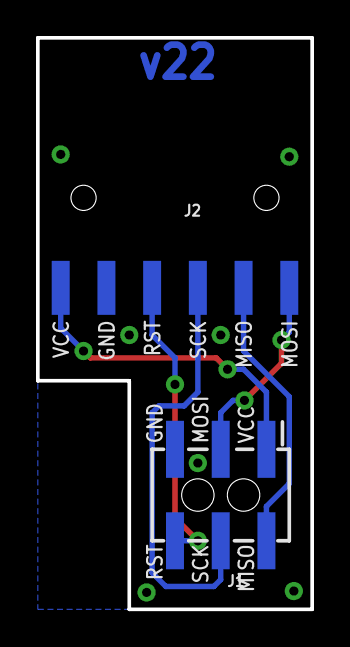
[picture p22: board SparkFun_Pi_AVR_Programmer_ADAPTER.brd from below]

Board: 2 copper layers, 15.2 x 31.8 mm, 16 parts (2 on the bottom side), 6 nets.

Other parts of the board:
U$1: GND1
U$2: MISO5
U$3: MOSI4
U$4: RST2
U$5: SCK3
U$6: VCC0
U$7: PI0
U$8: AVR1
U$9: PROGRAMMER2
U$10: HAT3
U$11: ADAPTER4

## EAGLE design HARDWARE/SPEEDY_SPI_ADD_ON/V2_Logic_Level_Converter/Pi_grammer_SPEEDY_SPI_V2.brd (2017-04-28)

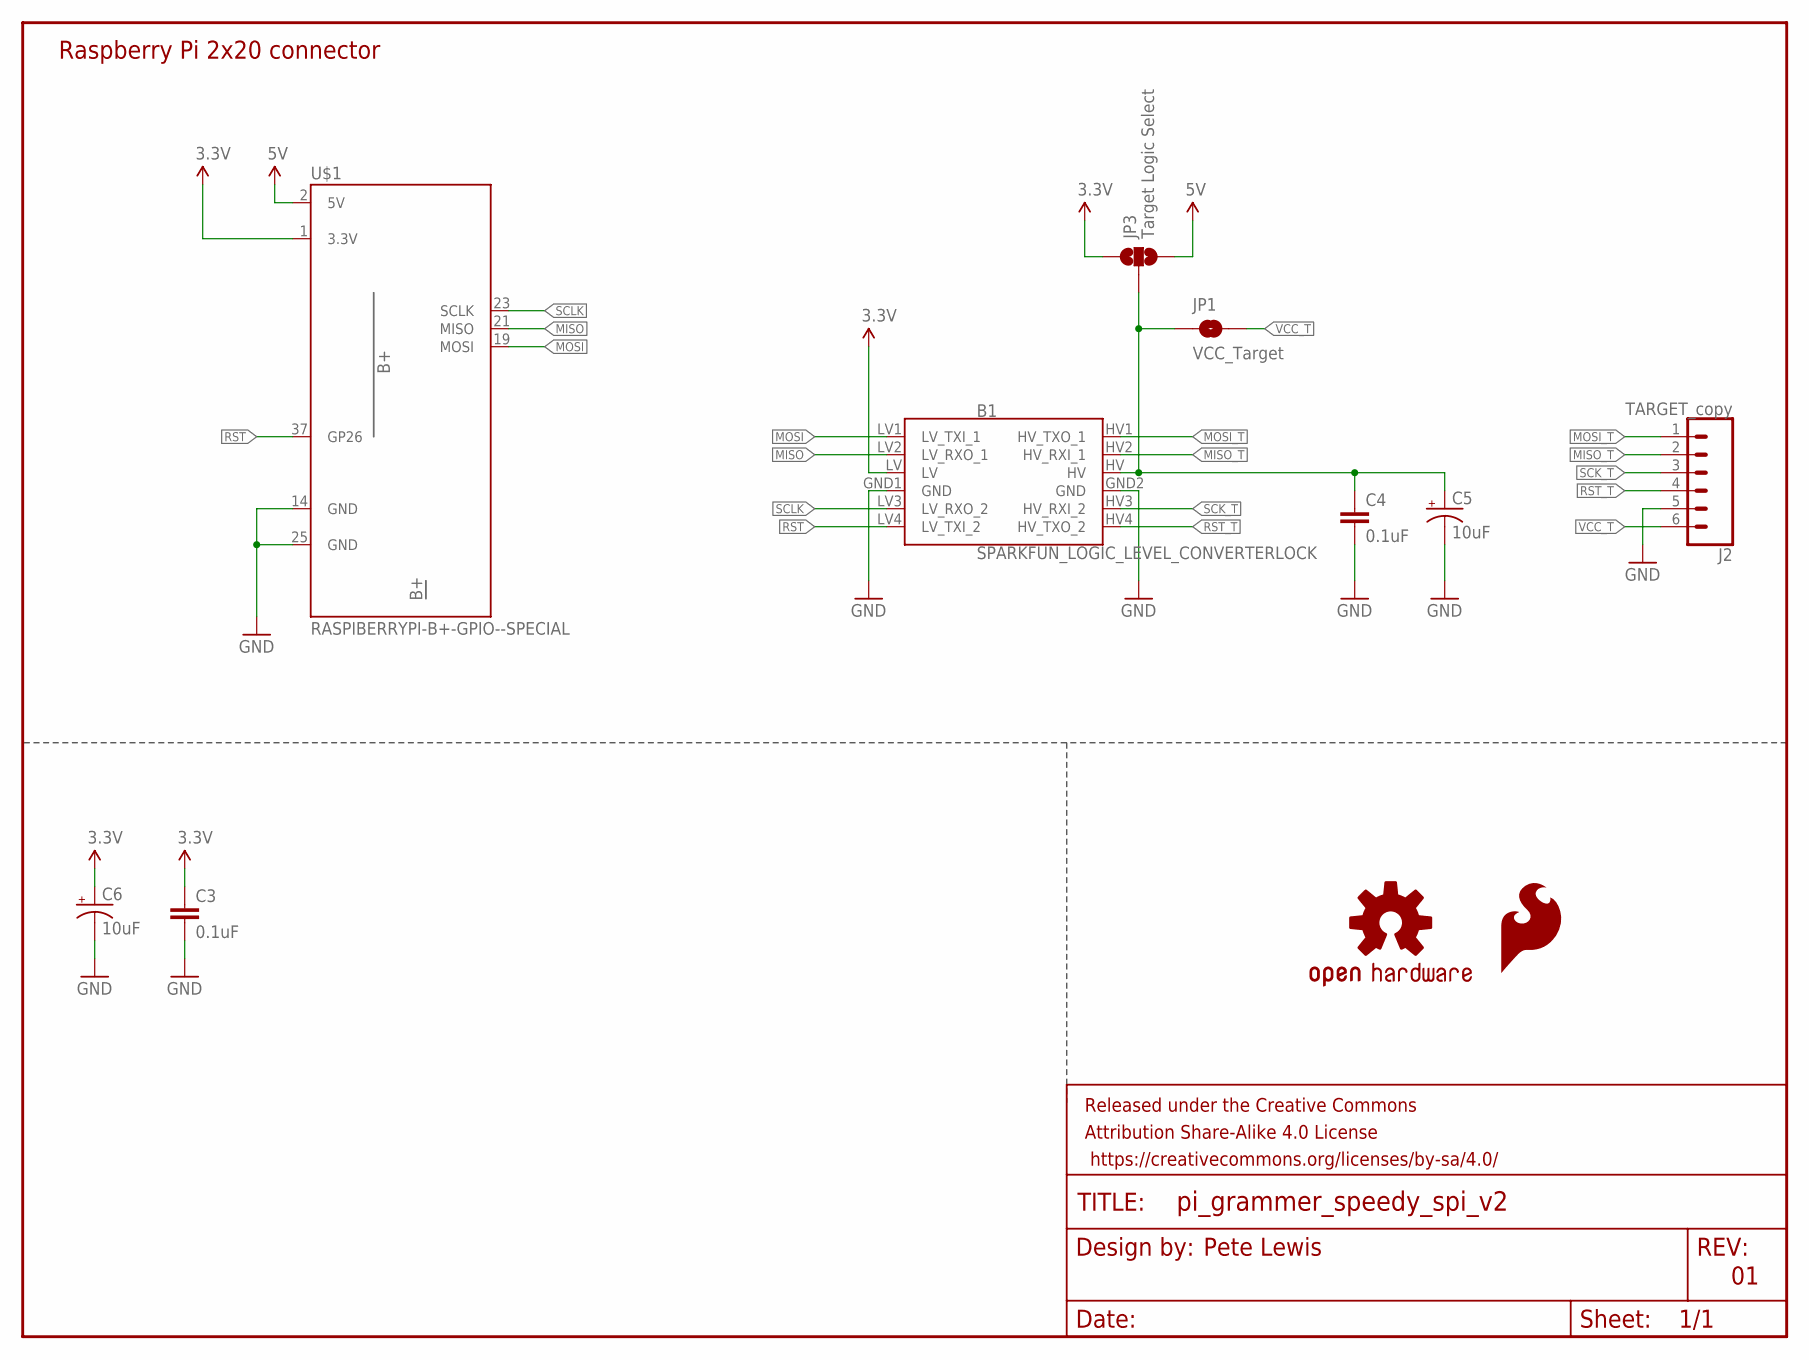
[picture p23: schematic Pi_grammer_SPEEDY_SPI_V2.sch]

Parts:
B1: SPARKFUN_LOGIC_LEVEL_CONVERTERLOCK; SPARKFUN_LOGIC_LEVEL_CONVERTER_LOCK
C3, C4: 0.1uF; 0603
C5, C6: 10uF; EIA3216
FRAME1: FRAME-LETTER; CREATIVE_COMMONS
J2: TARGET_copy; 1X06-SIP_LOCK
JP1: VCC_Target; SMT-JUMPER_2_NO_SILK
JP3: Target Logic Select; SMT-JUMPER_3_NO_SILK
LOGO1: SFE_LOGO_FLAME.1_INCH; SFE_LOGO_FLAME_.1
LOGO2: OSHW-LOGOS; OSHW-LOGO-S
U$1: RASPIBERRYPI-B+-GPIO--SPECIAL; 2X20-SHROUDED--SPECIAL

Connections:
3.3V: B1.LV, C3.1, C6.+, JP3.1, U$1.1 (3.3V)
5V: JP3.3, U$1.2 (5V)
GND: B1.GND1 (GND), B1.GND2 (GND), C3.2, C4.2, C5.-, C6.-, J2.5, U$1.14 (GND), U$1.25 (GND)
MISO: B1.LV2 (LV_RXO_1), U$1.21 (MISO)
MISO_T: B1.HV2 (HV_RXI_1), J2.2
MOSI: B1.LV1 (LV_TXI_1), U$1.19 (MOSI)
MOSI_T: B1.HV1 (HV_TXO_1), J2.1
unnamed: B1.HV, C4.1, C5.+, JP1.1, JP3.2
RST: B1.LV4 (LV_TXI_2), U$1.37 (GP26)
RST_T: B1.HV4 (HV_TXO_2), J2.4
SCK_T: B1.HV3 (HV_RXI_2), J2.3
SCLK: B1.LV3 (LV_RXO_2), U$1.23 (SCLK)
VCC_T: J2.6, JP1.2

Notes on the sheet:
Raspberry Pi 2x20 connector
Pete Lewis

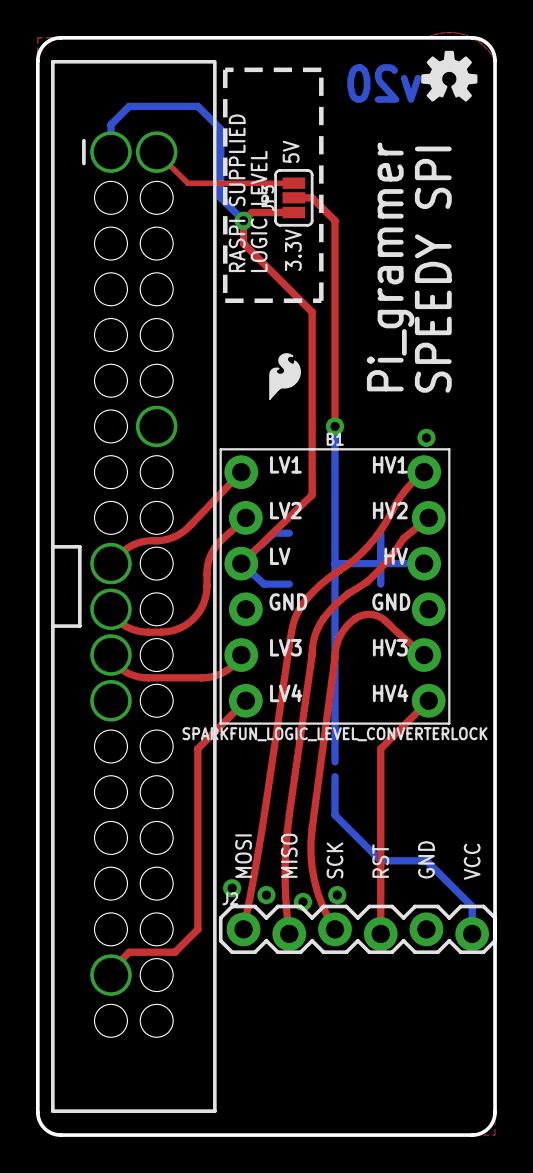
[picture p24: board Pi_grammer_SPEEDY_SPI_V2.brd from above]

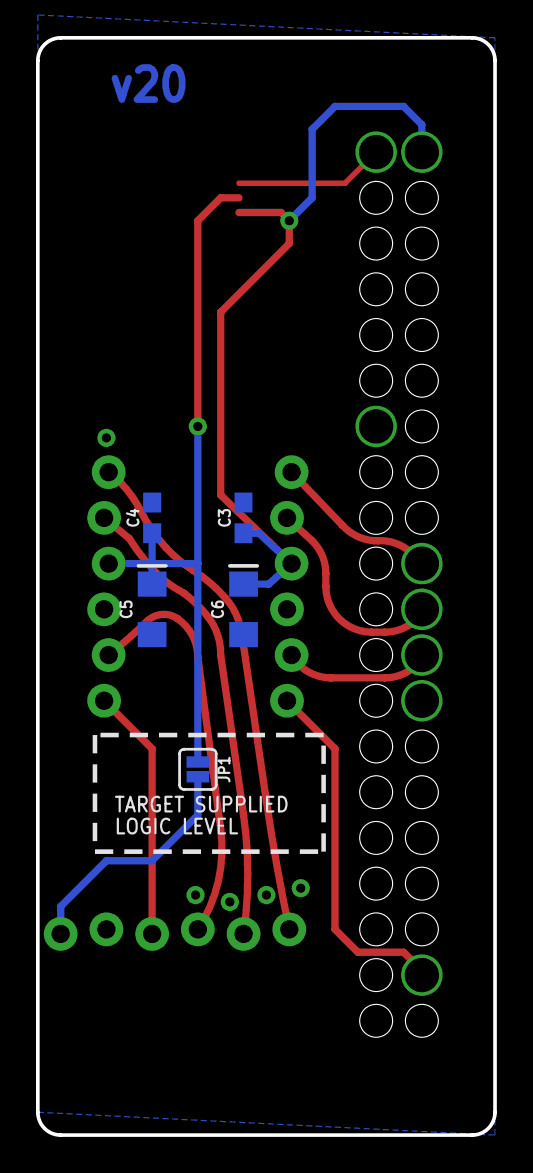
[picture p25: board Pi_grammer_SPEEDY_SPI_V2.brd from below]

Board: 2 copper layers, 25.4 x 61.0 mm, 12 parts (5 on the bottom side), 13 nets.

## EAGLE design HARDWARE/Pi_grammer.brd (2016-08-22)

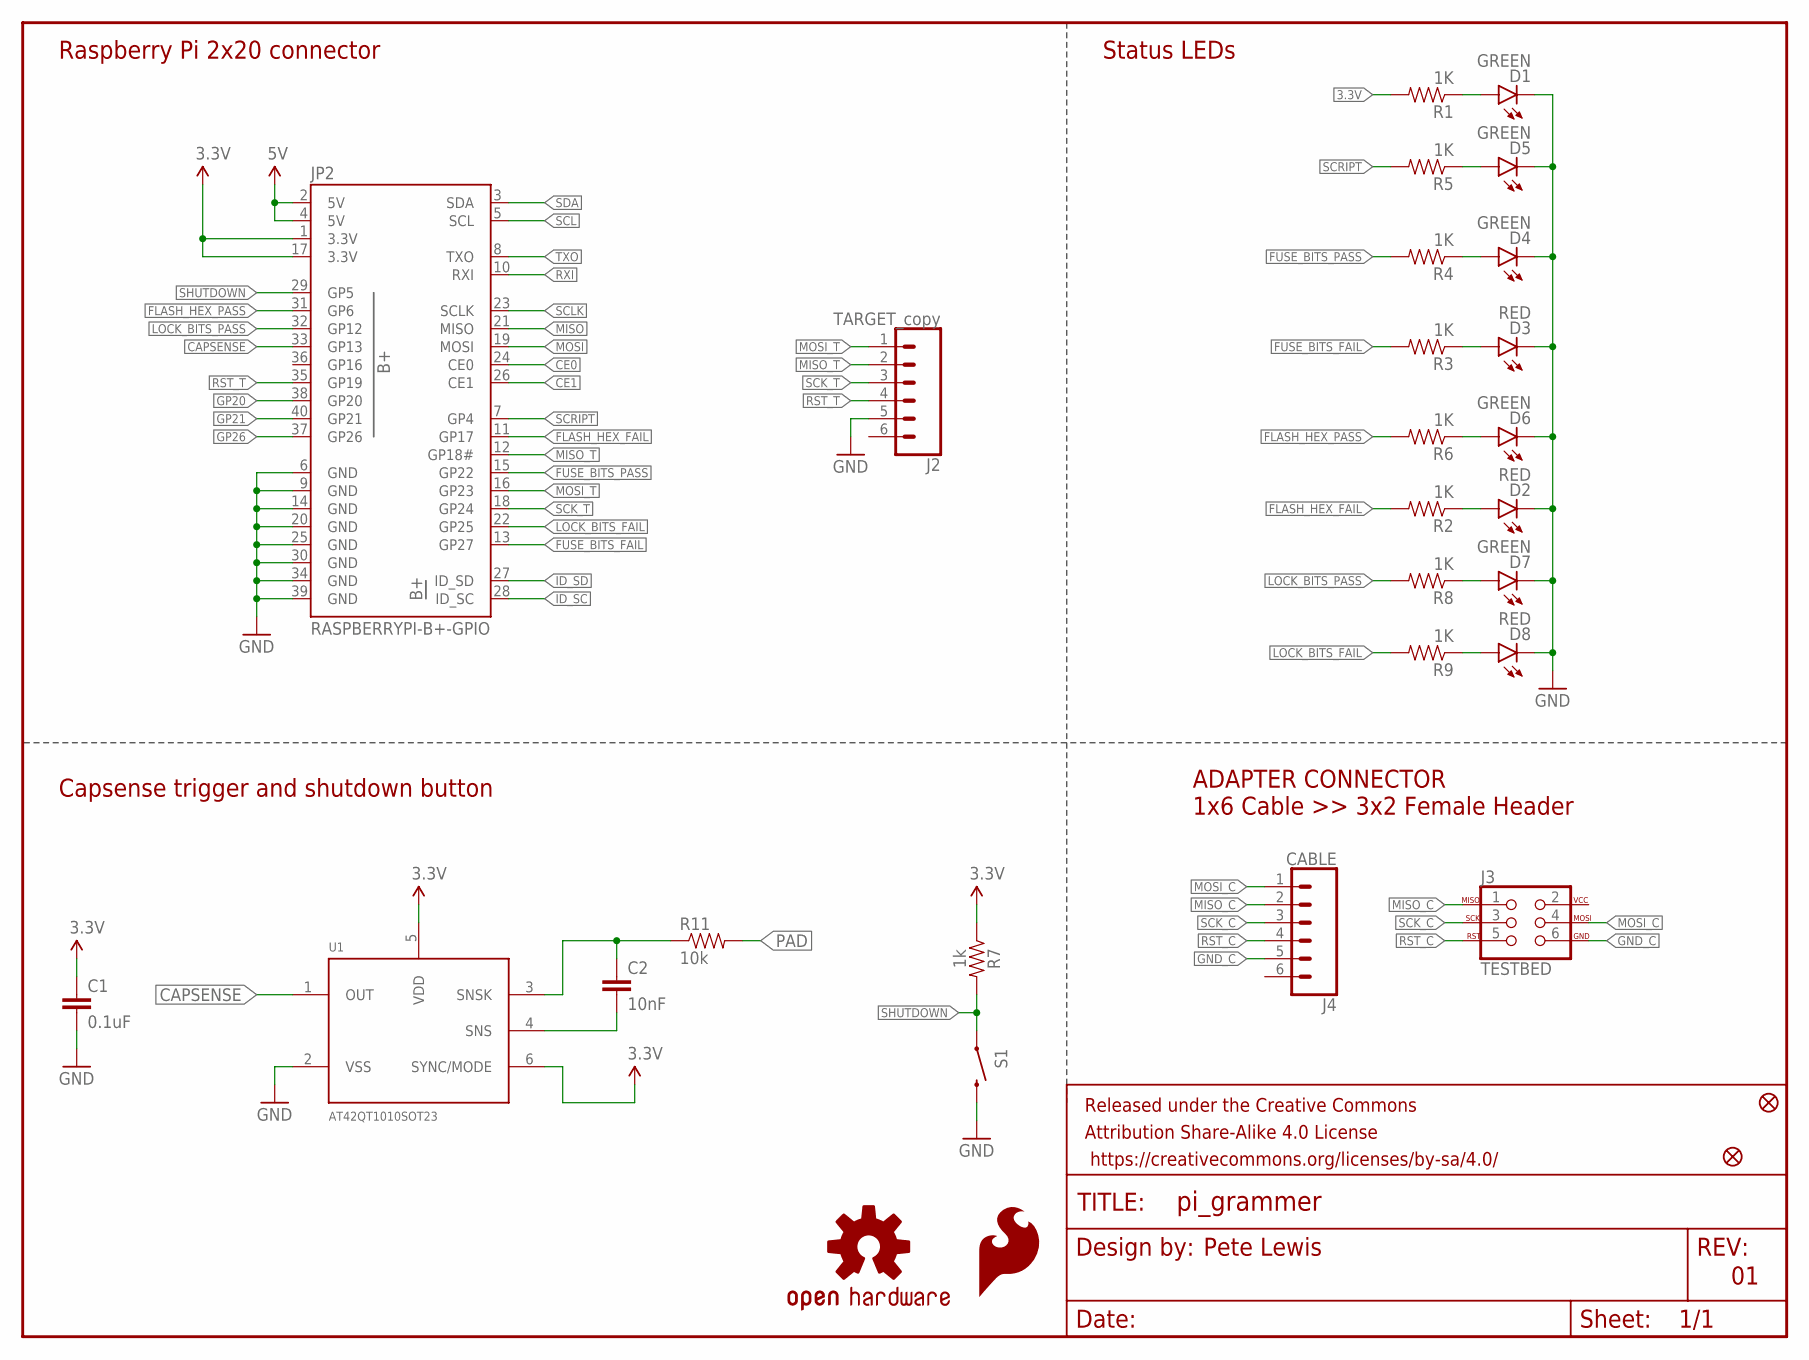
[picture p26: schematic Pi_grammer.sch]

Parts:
C1: 0.1uF; 0603-CAP
C2: 10nF; 0603-CAP
D1, D4, D5, D6, D7: GREEN; LED-1206
D2, D3, D8: RED; LED-1206
FD1, FD2: FIDUCIALUFIDUCIAL; FIDUCIAL-MICRO
FRAME1: FRAME-LETTER; CREATIVE_COMMONS
J2: TARGET_copy; MOLEX-1X6
J3: TESTBED; 2X3_LOCK
J4: CABLE; MOLEX-1X6-RA
JP2: RASPBERRYPI-B+-GPIO; 2X20-SHROUDED
LOGO1: SFE_LOGO_FLAME.1_INCH; SFE_LOGO_FLAME_.1
LOGO2: OSHW-LOGOS; OSHW-LOGO-S
R1, R2, R3, R4, R5, R6, R8, R9: 1K; 0603-RES
R7: 1k; 0603
R11: 10k; 0603-RES
S1: SWITCH-MOMENTARY-2SMD; TACTILE-SWITCH-SMD
U1: AT42QT1010SOT23; SOT23-6

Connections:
3.3V: C1.1, JP2.1 (3.3V), JP2.17 (3.3V), R1.2, R7.1, U1.5 (VDD), U1.6 (SYNC/MODE)
5V: JP2.2 (5V), JP2.4 (5V)
CAPSENSE: JP2.33 (GP13), U1.1 (OUT)
CE0: JP2.24 (CE0)
CE1: JP2.26 (CE1)
FLASH_HEX_FAIL: JP2.11 (GP17), R2.2
FLASH_HEX_PASS: JP2.31 (GP6), R6.2
FUSE_BITS_FAIL: JP2.13 (GP27), R3.2
FUSE_BITS_PASS: JP2.15 (GP22), R4.2
GND: C1.2, D1.C, D2.C, D3.C, D4.C, D5.C, D6.C, D7.C, D8.C, J2.5, JP2.6 (GND), JP2.9 (GND), JP2.14 (GND), JP2.20 (GND), JP2.25 (GND), JP2.30 (GND), JP2.34 (GND), JP2.39 (GND), S1.3 (2), U1.2 (VSS)
GND_C: J3.6, J4.5
GP20: JP2.38 (GP20)
GP21: JP2.40 (GP21)
GP26: JP2.37 (GP26)
ID_SC: JP2.28 (ID_SC)
ID_SD: JP2.27 (ID_SD)
LOCK_BITS_FAIL: JP2.22 (GP25), R9.2
LOCK_BITS_PASS: JP2.32 (GP12), R8.2
MISO: JP2.21 (MISO)
MISO_C: J3.1, J4.2
MISO_T: J2.2, JP2.12 (GP18#)
MOSI: JP2.19 (MOSI)
MOSI_C: J3.4, J4.1
MOSI_T: J2.1, JP2.16 (GP23)
unnamed: D6.A, R6.1
unnamed: D1.A, R1.1
unnamed: D2.A, R2.1
unnamed: D3.A, R3.1
unnamed: D7.A, R8.1
unnamed: D4.A, R4.1
unnamed: D5.A, R5.1
unnamed: D8.A, R9.1
unnamed: C2.2, U1.4 (SNS)
unnamed: C2.1, R11.1, U1.3 (SNSK)
PAD: R11.2
RST_C: J3.5, J4.4
RST_T: J2.4, JP2.35 (GP19)
RXI: JP2.10 (RXI)
SCK_C: J3.3, J4.3
SCK_T: J2.3, JP2.18 (GP24)
SCL: JP2.5 (SCL)
SCLK: JP2.23 (SCLK)
SCRIPT: JP2.7 (GP4), R5.2
SDA: JP2.3 (SDA)
SHUTDOWN: JP2.29 (GP5), R7.2, S1.1
TXO: JP2.8 (TXO)

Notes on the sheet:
ADAPTER CONNECTOR 1x6 Cable >> 3x2 Female Header
Raspberry Pi 2x20 connector
Pete Lewis
Status LEDs
Capsense trigger and shutdown button

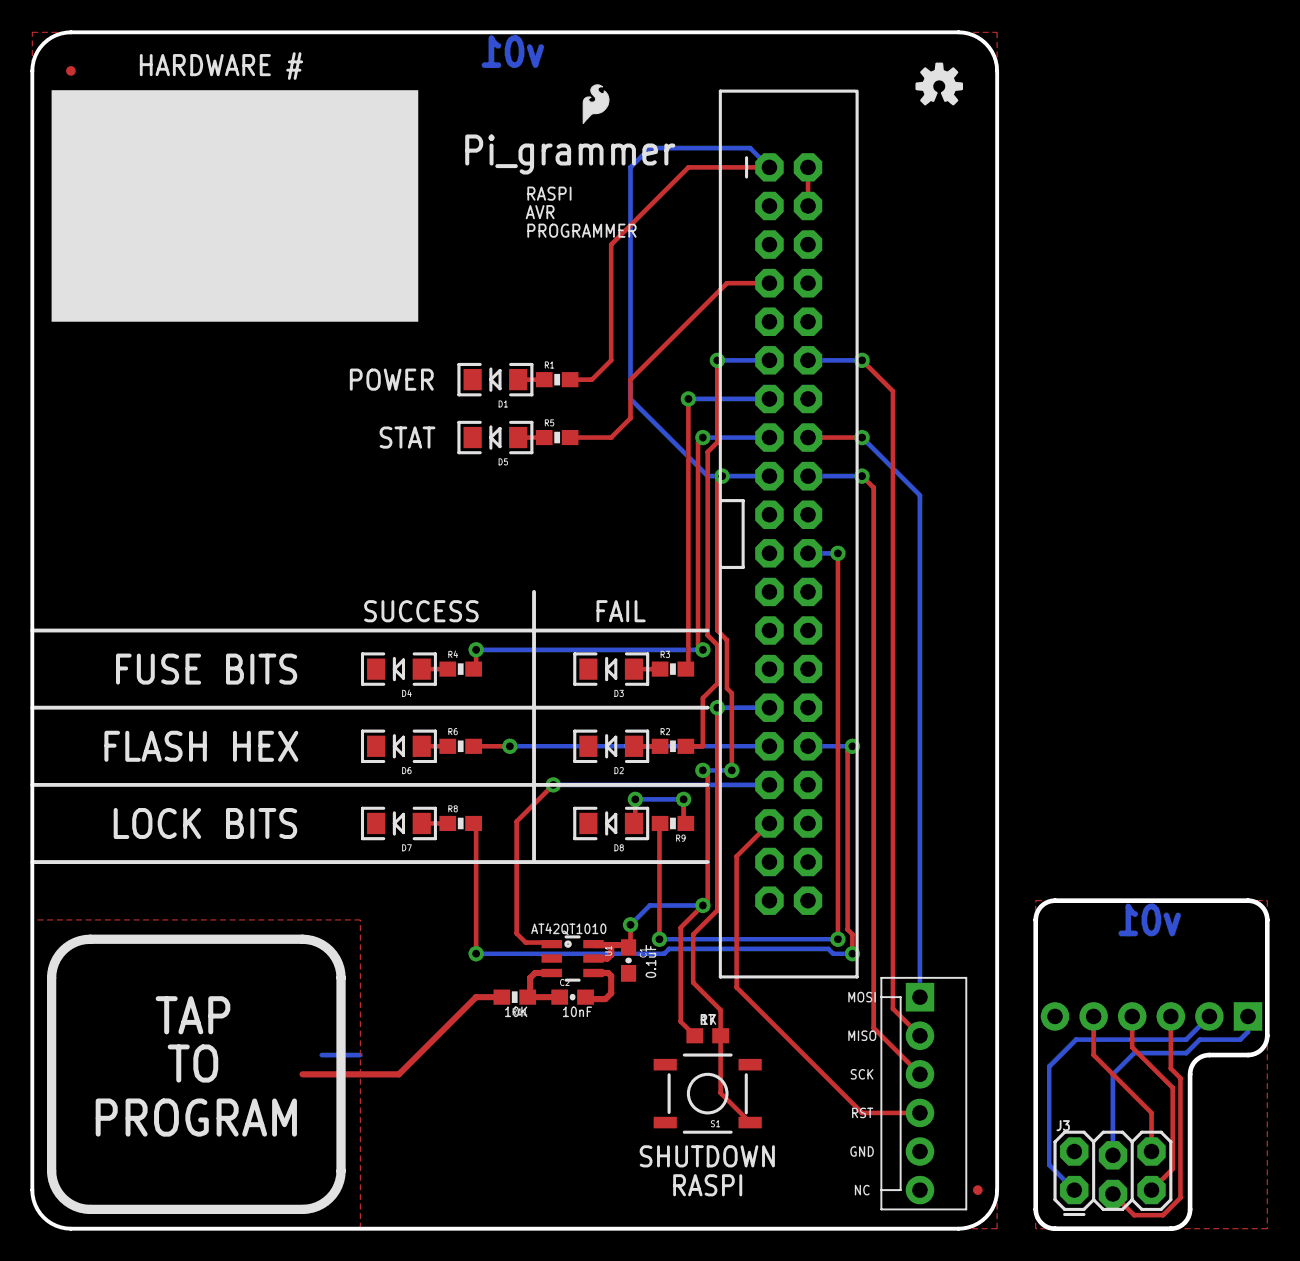
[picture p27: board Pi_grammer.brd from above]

Board: 2 copper layers, 63.5 x 78.7 mm, 31 parts (1 on the bottom side), 31 nets.

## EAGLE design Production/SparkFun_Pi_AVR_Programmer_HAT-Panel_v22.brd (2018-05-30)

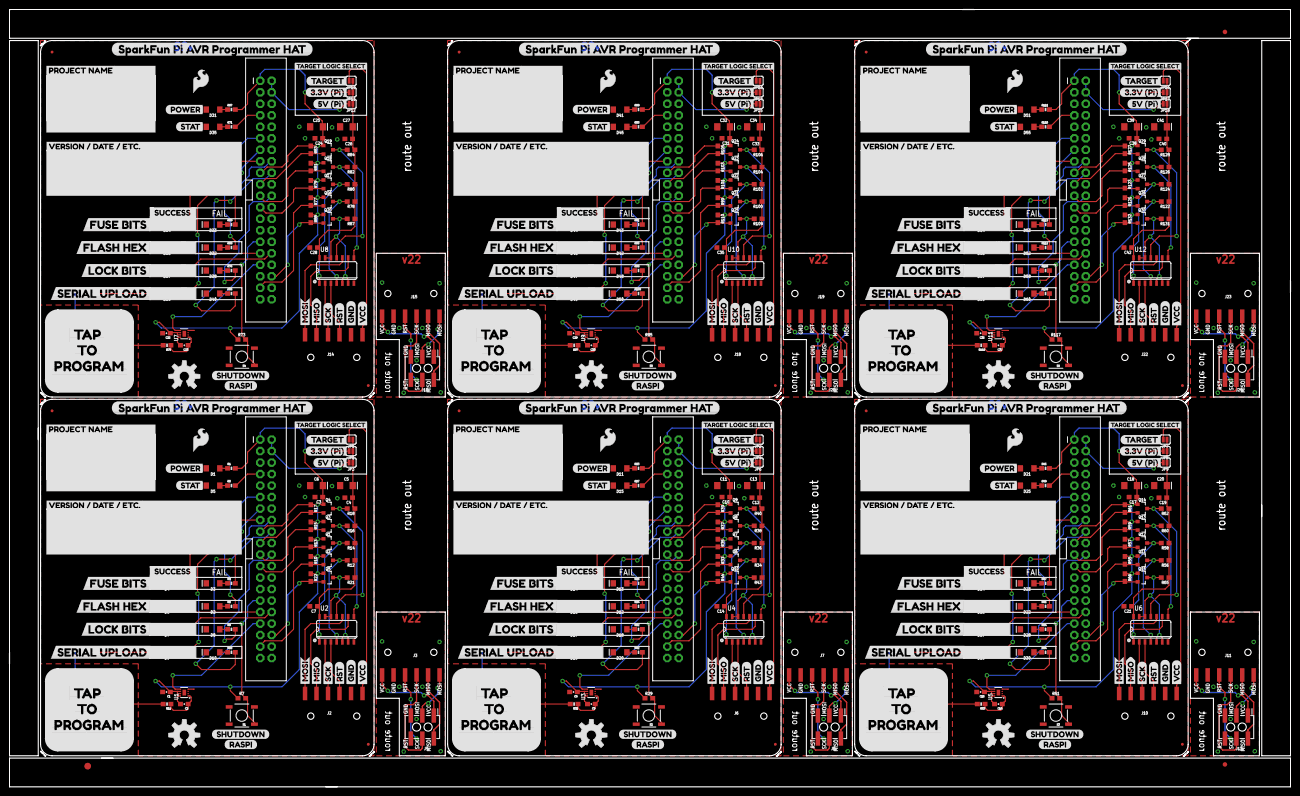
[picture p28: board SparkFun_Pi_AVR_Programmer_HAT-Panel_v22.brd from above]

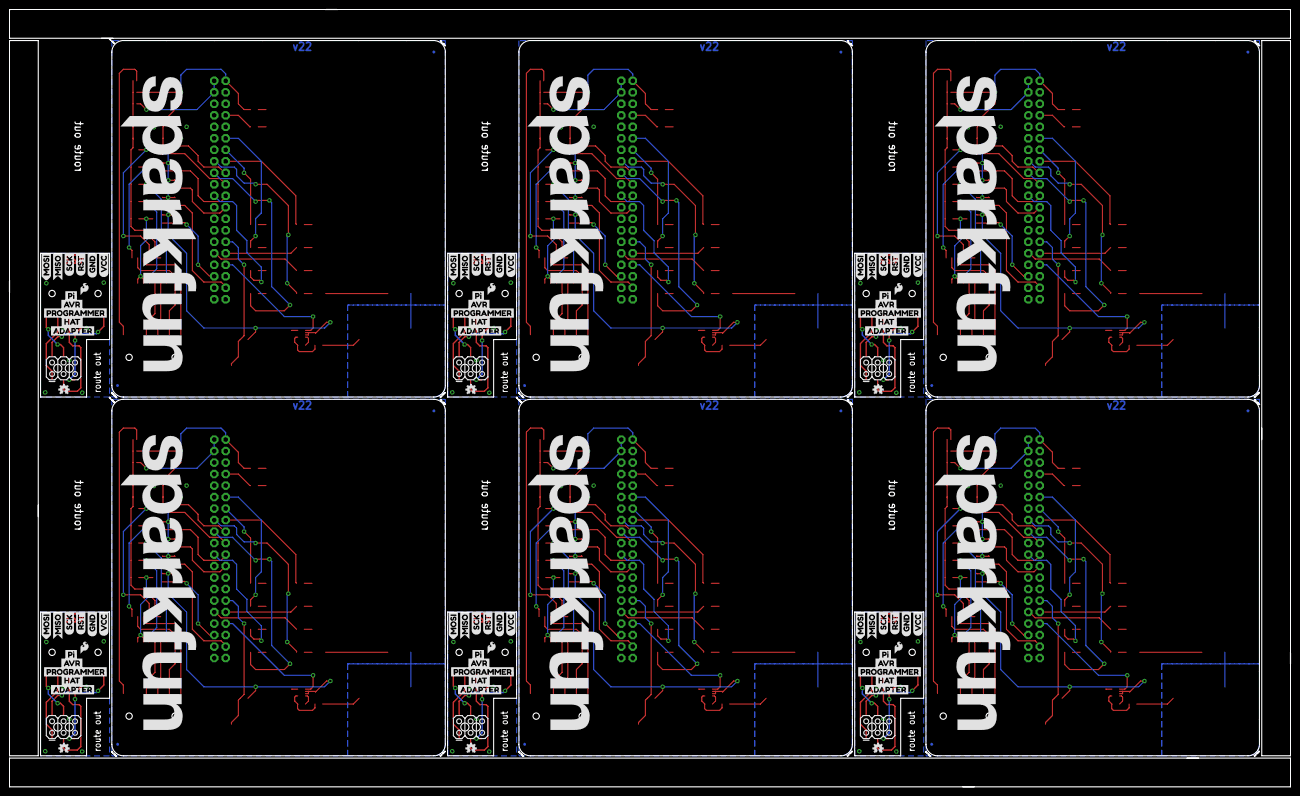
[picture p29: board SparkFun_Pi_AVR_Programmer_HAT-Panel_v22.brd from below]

Board: 2 copper layers, 283.0 x 171.7 mm, 597 parts (96 on the bottom side), 288 nets.

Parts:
C1, C8, C15, C22, C29, C36: 0.1uF; 0603-CAP
C2, C9, C16, C23, C30, C37: 10nF; 0603-CAP
C3, C4, C7, C10, C12, C14, C17, C19, C21, C24, C26, C28, C31, C33, C35, C38, C40, C42: 0.1uF; 0603
C5, C6, C11, C13, C18, C20, C25, C27, C32, C34, C39, C41: 10uF; EIA3216
D1, D4, D5, D6, D7, D9, D11, D14, D15, D16, D17, D19, D21, D24, D25, D26, D27, D29, D31, D34, D35, D36, D37, D39, D41, D44, D45, D46, D47, D49, D51, D54, D55, D56, D57, D59: GREEN; LED-1206
D2, D3, D8, D10, D12, D13, D18, D20, D22, D23, D28, D30, D32, D33, D38, D40, D42, D43, D48, D50, D52, D53, D58, D60: RED; LED-1206
E$1: FIDUCIAL-1.5X3
E$5, E$6: FIDUCIAL-1X2
FD1, FD2, FD3, FD4, FD5, FD6, FD7, FD8, FD9, FD10, FD11, FD12, FD13, FD14, FD15, FD16, FD17, FD18, FD19, FD20, FD21, FD22, FD23, FD24: FIDUCIALUFIDUCIAL; FIDUCIAL-MICRO
J1, J5, J9, J13, J17, J21: RASPBERRYPI-B+-GPIO; 2X20-SHROUDED
J2, J6, J10, J14, J18, J22: SPI; 1X06-SMD_RA_MALE
J3, J7, J11, J15, J19, J23: CABLE; 1X06-SMD_RA_MALE
J4, J8, J12, J16, J20, J24: AVR 3X2 TARGET; 2X3_SMT_POSTS
JP1, JP3, JP4, JP6, JP8, JP9, JP11, JP12, JP14, JP15, JP17, JP18: SMT-JUMPER_2_NO_SILK
JP2, JP5, JP7, JP10, JP13, JP16: SMT-JUMPER_2_NC_PASTE_SILK
LOGO1, LOGO7, LOGO12, LOGO17, LOGO22, LOGO27: SFE_LOGO_FLAME.2_INCH; SFE_LOGO_FLAME_.2
LOGO2, LOGO6, LOGO11, LOGO16, LOGO21, LOGO26: OSHW-LOGOL; OSHW-LOGO-L
LOGO3, LOGO8, LOGO13, LOGO18, LOGO23, LOGO28: SFE_LOGO_NAME.6_INCH; SFE_LOGO_NAME_.6
LOGO4, LOGO9, LOGO14, LOGO19, LOGO24, LOGO29: SFE_LOGO_FLAME.1_INCH; SFE_LOGO_FLAME_.1
LOGO5, LOGO10, LOGO15, LOGO20, LOGO25, LOGO30: OSHW-LOGOMINI; OSHW-LOGO-MINI
Q1, Q2, Q3, Q4, Q5, Q6, Q7, Q8, Q9, Q10, Q11, Q12, Q13, Q14, Q15, Q16, Q17, Q18, Q19, Q20, Q21, Q22, Q23, Q24, Q25, Q26, Q27, Q28, Q29, Q30: 220mA/50V/3.5Ω; SOT23-3
R1, R2, R3, R4, R5, R6, R8, R9, R19, R20, R23, R24, R25, R26, R27, R28, R30, R32, R41, R42, R45, R46, R47, R48, R49, R50, R52, R54, R63, R64, R67, R68, R69, R70, R71, R72, R74, R76, R85, R86, R89, R90, R91, R92, R93, R94, R96, R98, R107, R108, R111, R112, R113, R114, R115, R116, R118, R120, R129, R130: 1K; 0603-RES
R7, R29, R51, R73, R95, R117: 1k; 0603
R10, R12, R13, R14, R15, R16, R17, R18, R21, R22, R33, R34, R35, R36, R37, R38, R39, R40, R43, R44, R55, R56, R57, R58, R59, R60, R61, R62, R65, R66, R77, R78, R79, R80, R81, R82, R83, R84, R87, R88, R99, R100, R101, R102, R103, R104, R105, R106, R109, R110, R121, R122, R123, R124, R125, R126, R127, R128, R131, R132: 10k; 0603
R11, R31, R53, R75, R97, R119: 10k; 0603-RES
S1, S2, S3, S4, S5, S6: TACTILE-SWITCH-SMD
U1, U3, U5, U7, U9, U11: AT42QT1010 - UDFN; UDFN/USON_8_PAD
U2, U4, U6, U8, U10, U12: 74LVC4066; SO14
U$1, U$37, U$73, U$109, U$145, U$181: SPARKFUN_PI_AVR_PROGRAMMER_HAT0
U$2, U$38, U$74, U$110, U$146, U$182: PROJECT_NAME0
U$3, U$39, U$75, U$111, U$147, U$183: VERSION_#_DATE_#_ETC#0
U$4, U$40, U$76, U$112, U$148, U$184: TARGET_LOGIC_SELECT4
U$5, U$41, U$77, U$113, U$149, U$185: POWER0
U$6, U$42, U$78, U$114, U$150, U$186: STAT1
U$7, U$43, U$79, U$115, U$151, U$187: SHUTDOWN2
U$8, U$44, U$80, U$116, U$152, U$188: RASPI3
U$9, U$45, U$81, U$117, U$153, U$189: 3#3V_#PI#7
U$10, U$46, U$82, U$118, U$154, U$190: 5V_#PI#8
U$11, U$47, U$83, U$119, U$155, U$191: TARGET0
U$12, U$48, U$84, U$120, U$156, U$192: MISO1
U$13, U$49, U$85, U$121, U$157, U$193: MOSI0
U$14, U$50, U$86, U$122, U$158, U$194: SCK2
U$15, U$51, U$87, U$123, U$159, U$195: RST3
U$16, U$52, U$88, U$124, U$160, U$196: GND4
U$17, U$62, U$98, U$134, U$170, U$206: GND1
U$18, U$53, U$89, U$125, U$161, U$197: TAP0
U$19, U$54, U$90, U$126, U$162, U$198: TO1
U$20, U$55, U$91, U$127, U$163, U$199: PROGRAM2
U$21, U$31, U$61, U$67, U$97, U$103, U$133, U$139, U$169, U$175, U$205, U$211: VCC0
U$22, U$56, U$92, U$128, U$164, U$200: SUCCESS0
U$23, U$57, U$93, U$129, U$165, U$201: FUSE_BITS2
U$24, U$58, U$94, U$130, U$166, U$202: FLASH_HEX3
U$25, U$59, U$95, U$131, U$167, U$203: LOCK_BITS4
U$26, U$60, U$96, U$132, U$168, U$204: SERIAL_UPLOAD5
U$27, U$63, U$99, U$135, U$171, U$207: MISO5
U$28, U$64, U$100, U$136, U$172, U$208: MOSI4
U$29, U$65, U$101, U$137, U$173, U$209: RST2
U$30, U$66, U$102, U$138, U$174, U$210: SCK3
U$32, U$68, U$104, U$140, U$176, U$212: PI0
U$33, U$69, U$105, U$141, U$177, U$213: AVR1
U$34, U$70, U$106, U$142, U$178, U$214: PROGRAMMER2
U$35, U$71, U$107, U$143, U$179, U$215: HAT3
U$36, U$72, U$108, U$144, U$180, U$216: ADAPTER4

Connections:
3.3V: C1.1, C3.1, C6.+, J1.1, J1.17, JP1.2, Q1.1, Q2.1, Q3.1, Q4.1, Q5.1, R1.2, R7.1, R10.1, R13.1, R15.1, R17.1, R22.1, U1.6, U1.7
3.3V1: C8.1, C10.1, C11.+, J5.1, J5.17, JP4.2, Q6.1, Q7.1, Q8.1, Q9.1, Q10.1, R23.2, R29.1, R33.1, R35.1, R37.1, R39.1, R44.1, U3.6, U3.7
3.3V2: C15.1, C17.1, C18.+, J9.1, J9.17, JP8.2, Q11.1, Q12.1, Q13.1, Q14.1, Q15.1, R45.2, R51.1, R55.1, R57.1, R59.1, R61.1, R66.1, U5.6, U5.7
3.3V3: C22.1, C24.1, C25.+, J13.1, J13.17, JP11.2, Q16.1, Q17.1, Q18.1, Q19.1, Q20.1, R67.2, R73.1, R77.1, R79.1, R81.1, R83.1, R88.1, U7.6, U7.7
3.3V4: C29.1, C31.1, C32.+, J17.1, J17.17, JP14.2, Q21.1, Q22.1, Q23.1, Q24.1, Q25.1, R89.2, R95.1, R99.1, R101.1, R103.1, R105.1, R110.1, U9.6, U9.7
3.3V5: C36.1, C38.1, C39.+, J21.1, J21.17, JP17.2, Q26.1, Q27.1, Q28.1, Q29.1, Q30.1, R111.2, R117.1, R121.1, R123.1, R125.1, R127.1, R132.1, U11.6, U11.7
5V: J1.2, J1.4, JP3.2
5V1: J5.2, J5.4, JP6.2
5V2: J9.2, J9.4, JP9.2
5V3: J13.2, J13.4, JP12.2
5V4: J17.2, J17.4, JP15.2
5V5: J21.2, J21.4, JP18.2
BRD_MISO: J2.2, U2.9
BRD_MISO1: J6.2, U4.9
BRD_MISO2: J10.2, U6.9
BRD_MISO3: J14.2, U8.9
BRD_MISO4: J18.2, U10.9
BRD_MISO5: J22.2, U12.9
BRD_MOSI: J2.1, U2.10
BRD_MOSI1: J6.1, U4.10
BRD_MOSI2: J10.1, U6.10
BRD_MOSI3: J14.1, U8.10
BRD_MOSI4: J18.1, U10.10
BRD_MOSI5: J22.1, U12.10
BRD_RST: J2.4, U2.3
BRD_RST1: J6.4, U4.3
BRD_RST2: J10.4, U6.3
BRD_RST3: J14.4, U8.3
BRD_RST4: J18.4, U10.3
BRD_RST5: J22.4, U12.3
BRD_SCK: J2.3, U2.2
BRD_SCK1: J6.3, U4.2
BRD_SCK2: J10.3, U6.2
BRD_SCK3: J14.3, U8.2
BRD_SCK4: J18.3, U10.2
BRD_SCK5: J22.3, U12.2
CAPSENSE: J1.33, U1.5
CAPSENSE1: J5.33, U3.5
CAPSENSE2: J9.33, U5.5
CAPSENSE3: J13.33, U7.5
CAPSENSE4: J17.33, U9.5
CAPSENSE5: J21.33, U11.5
FLASH_HEX_FAIL: J1.11, R2.2
FLASH_HEX_FAIL1: J5.11, R24.2
FLASH_HEX_FAIL2: J9.11, R46.2
FLASH_HEX_FAIL3: J13.11, R68.2
FLASH_HEX_FAIL4: J17.11, R90.2
FLASH_HEX_FAIL5: J21.11, R112.2
FLASH_HEX_PASS: J1.31, R6.2
FLASH_HEX_PASS1: J5.31, R28.2
FLASH_HEX_PASS2: J9.31, R50.2
FLASH_HEX_PASS3: J13.31, R72.2
FLASH_HEX_PASS4: J17.31, R94.2
FLASH_HEX_PASS5: J21.31, R116.2
FUSE_BITS_FAIL: J1.13, R3.2
FUSE_BITS_FAIL1: J5.13, R25.2
FUSE_BITS_FAIL2: J9.13, R47.2
FUSE_BITS_FAIL3: J13.13, R69.2
FUSE_BITS_FAIL4: J17.13, R91.2
FUSE_BITS_FAIL5: J21.13, R113.2
FUSE_BITS_PASS: J1.15, R4.2
FUSE_BITS_PASS1: J5.15, R26.2
FUSE_BITS_PASS2: J9.15, R48.2
FUSE_BITS_PASS3: J13.15, R70.2
FUSE_BITS_PASS4: J17.15, R92.2
FUSE_BITS_PASS5: J21.15, R114.2
GND: C1.2, C3.2, C4.2, C5.-, C6.-, C7.2, D1.C, D2.C, D3.C, D4.C, D5.C, D6.C, D7.C, D8.C, D9.C, D10.C, J1.6, J1.9, J1.14, J1.20, J1.25, J1.30, J1.34, J1.39, J2.5, S1.3, U1.4, U2.7
GND1: C8.2, C10.2, C11.-, C12.2, C13.-, C14.2, D11.C, D12.C, D13.C, D14.C, D15.C, D16.C, D17.C, D18.C, D19.C, D20.C, J5.6, J5.9, J5.14, J5.20, J5.25, J5.30, J5.34, J5.39, J6.5, S2.3, U3.4, U4.7
GND2: C15.2, C17.2, C18.-, C19.2, C20.-, C21.2, D21.C, D22.C, D23.C, D24.C, D25.C, D26.C, D27.C, D28.C, D29.C, D30.C, J9.6, J9.9, J9.14, J9.20, J9.25, J9.30, J9.34, J9.39, J10.5, S3.3, U5.4, U6.7
GND3: C22.2, C24.2, C25.-, C26.2, C27.-, C28.2, D31.C, D32.C, D33.C, D34.C, D35.C, D36.C, D37.C, D38.C, D39.C, D40.C, J13.6, J13.9, J13.14, J13.20, J13.25, J13.30, J13.34, J13.39, J14.5, S4.3, U7.4, U8.7
GND4: C29.2, C31.2, C32.-, C33.2, C34.-, C35.2, D41.C, D42.C, D43.C, D44.C, D45.C, D46.C, D47.C, D48.C, D49.C, D50.C, J17.6, J17.9, J17.14, J17.20, J17.25, J17.30, J17.34, J17.39, J18.5, S5.3, U9.4, U10.7
GND5: C36.2, C38.2, C39.-, C40.2, C41.-, C42.2, D51.C, D52.C, D53.C, D54.C, D55.C, D56.C, D57.C, D58.C, D59.C, D60.C, J21.6, J21.9, J21.14, J21.20, J21.25, J21.30, J21.34, J21.39, J22.5, S6.3, U11.4, U12.7
GND_C: J3.5, J4.5
GND_C1: J7.5, J8.5
GND_C2: J11.5, J12.5
GND_C3: J15.5, J16.5
GND_C4: J19.5, J20.5
GND_C5: J23.5, J24.5
LOCK_BITS_FAIL: J1.22, R9.2
LOCK_BITS_FAIL1: J5.22, R32.2
LOCK_BITS_FAIL2: J9.22, R54.2
LOCK_BITS_FAIL3: J13.22, R76.2
LOCK_BITS_FAIL4: J17.22, R98.2
LOCK_BITS_FAIL5: J21.22, R120.2
LOCK_BITS_PASS: J1.32, R8.2
LOCK_BITS_PASS1: J5.32, R30.2
LOCK_BITS_PASS2: J9.32, R52.2
LOCK_BITS_PASS3: J13.32, R74.2
LOCK_BITS_PASS4: J17.32, R96.2
LOCK_BITS_PASS5: J21.32, R118.2
MISO: J1.21, Q3.2, R15.2
MISO1: J5.21, Q8.2, R37.2
MISO2: J9.21, Q13.2, R59.2
MISO3: J13.21, Q18.2, R81.2
MISO4: J17.21, Q23.2, R103.2
MISO5: J21.21, Q28.2, R125.2
MISO_C: J3.2, J4.2
MISO_C1: J7.2, J8.2
MISO_C2: J11.2, J12.2
MISO_C3: J15.2, J16.2
MISO_C4: J19.2, J20.2
MISO_C5: J23.2, J24.2
MISO_T: Q3.3, R16.2, U2.8
MISO_T1: Q8.3, R38.2, U4.8
MISO_T2: Q13.3, R60.2, U6.8
MISO_T3: Q18.3, R82.2, U8.8
MISO_T4: Q23.3, R104.2, U10.8
MISO_T5: Q28.3, R126.2, U12.8
MOSI: J1.19, Q4.2, R17.2
MOSI1: J5.19, Q9.2, R39.2
MOSI2: J9.19, Q14.2, R61.2
MOSI3: J13.19, Q19.2, R83.2
MOSI4: J17.19, Q24.2, R105.2
MOSI5: J21.19, Q29.2, R127.2
MOSI_C: J3.1, J4.3
MOSI_C1: J7.1, J8.3
MOSI_C2: J11.1, J12.3
MOSI_C3: J15.1, J16.3
MOSI_C4: J19.1, J20.3
MOSI_C5: J23.1, J24.3
MOSI_T: Q4.3, R18.2, U2.11
MOSI_T1: Q9.3, R40.2, U4.11
MOSI_T2: Q14.3, R62.2, U6.11
MOSI_T3: Q19.3, R84.2, U8.11
MOSI_T4: Q24.3, R106.2, U10.11
MOSI_T5: Q29.3, R128.2, U12.11
unnamed: D6.A, R6.1
unnamed: D1.A, R1.1
unnamed: D2.A, R2.1
unnamed: D3.A, R3.1
unnamed: D7.A, R8.1
unnamed: D4.A, R4.1
unnamed: D5.A, R5.1
unnamed: D8.A, R9.1
unnamed: D11.A, R23.1
unnamed: C2.2, U1.8
unnamed: C2.1, R11.1, U1.1
unnamed: D12.A, R24.1
unnamed: D9.A, R19.1
unnamed: D10.A, R20.1
unnamed: D13.A, R25.1
unnamed: D14.A, R26.1
unnamed: D15.A, R27.1
unnamed: D16.A, R28.1
unnamed: D17.A, R30.1
unnamed: C9.2, U3.8
unnamed: C9.1, R31.1, U3.1
unnamed: D18.A, R32.1
unnamed: D19.A, R41.1
unnamed: D20.A, R42.1
unnamed: D21.A, R45.1
unnamed: D22.A, R46.1
unnamed: D23.A, R47.1
unnamed: D24.A, R48.1
unnamed: D25.A, R49.1
unnamed: D26.A, R50.1
unnamed: D27.A, R52.1
unnamed: C16.2, U5.8
unnamed: C16.1, R53.1, U5.1
unnamed: D28.A, R54.1
unnamed: D29.A, R63.1
unnamed: D30.A, R64.1
unnamed: D31.A, R67.1
unnamed: D32.A, R68.1
unnamed: D33.A, R69.1
unnamed: D34.A, R70.1
unnamed: D35.A, R71.1
unnamed: D36.A, R72.1
unnamed: D37.A, R74.1
unnamed: C23.2, U7.8
unnamed: C23.1, R75.1, U7.1
unnamed: D38.A, R76.1
unnamed: D39.A, R85.1
unnamed: D40.A, R86.1
unnamed: D41.A, R89.1
unnamed: D42.A, R90.1
unnamed: D43.A, R91.1
unnamed: D44.A, R92.1
unnamed: D45.A, R93.1
unnamed: D46.A, R94.1
unnamed: D47.A, R96.1
unnamed: C30.2, U9.8
unnamed: C30.1, R97.1, U9.1
unnamed: D48.A, R98.1
unnamed: D49.A, R107.1
unnamed: D50.A, R108.1
unnamed: D51.A, R111.1
unnamed: D52.A, R112.1
unnamed: D53.A, R113.1
unnamed: D54.A, R114.1
unnamed: D55.A, R115.1
unnamed: D56.A, R116.1
unnamed: D57.A, R118.1
unnamed: C37.2, U11.8
unnamed: C37.1, R119.1, U11.1
unnamed: D58.A, R120.1
unnamed: D59.A, R129.1
unnamed: D60.A, R130.1
PGM_CTRL: J1.36, Q5.2, R22.2
PGM_CTRL1: J5.36, Q10.2, R44.2
PGM_CTRL2: J9.36, Q15.2, R66.2
PGM_CTRL3: J13.36, Q20.2, R88.2
PGM_CTRL4: J17.36, Q25.2, R110.2
PGM_CTRL5: J21.36, Q30.2, R132.2
PGM_CTRL_T: Q5.3, R21.2, U2.5, U2.6, U2.12, U2.13
PGM_CTRL_T1: Q10.3, R43.2, U4.5, U4.6, U4.12, U4.13
PGM_CTRL_T2: Q15.3, R65.2, U6.5, U6.6, U6.12, U6.13
PGM_CTRL_T3: Q20.3, R87.2, U8.5, U8.6, U8.12, U8.13
PGM_CTRL_T4: Q25.3, R109.2, U10.5, U10.6, U10.12, U10.13
PGM_CTRL_T5: Q30.3, R131.2, U12.5, U12.6, U12.12, U12.13
RST: J1.37, Q2.2, R10.2
RST1: J5.37, Q6.2, R33.2
RST2: J9.37, Q11.2, R55.2
RST3: J13.37, Q16.2, R77.2
RST4: J17.37, Q21.2, R99.2
RST5: J21.37, Q26.2, R121.2
RST_C: J3.4, J4.6
RST_C1: J7.4, J8.6
RST_C2: J11.4, J12.6
RST_C3: J15.4, J16.6
RST_C4: J19.4, J20.6
RST_C5: J23.4, J24.6
RST_T: Q2.3, R12.2, U2.4
RST_T1: Q6.3, R34.2, U4.4
RST_T2: Q11.3, R56.2, U6.4
RST_T3: Q16.3, R78.2, U8.4
RST_T4: Q21.3, R100.2, U10.4
RST_T5: Q26.3, R122.2, U12.4
SCK: J1.23, Q1.2, R13.2
SCK1: J5.23, Q7.2, R35.2
SCK2: J9.23, Q12.2, R57.2
SCK3: J13.23, Q17.2, R79.2
SCK4: J17.23, Q22.2, R101.2
SCK5: J21.23, Q27.2, R123.2
SCK_C: J3.3, J4.4
SCK_C1: J7.3, J8.4
SCK_C2: J11.3, J12.4
SCK_C3: J15.3, J16.4
SCK_C4: J19.3, J20.4
SCK_C5: J23.3, J24.4
SCK_T: Q1.3, R14.2, U2.1
SCK_T1: Q7.3, R36.2, U4.1
SCK_T2: Q12.3, R58.2, U6.1
SCK_T3: Q17.3, R80.2, U8.1
SCK_T4: Q22.3, R102.2, U10.1
SCK_T5: Q27.3, R124.2, U12.1
SCRIPT: J1.7, R5.2
SCRIPT1: J5.7, R27.2
SCRIPT2: J9.7, R49.2
SCRIPT3: J13.7, R71.2
SCRIPT4: J17.7, R93.2
SCRIPT5: J21.7, R115.2
SERIAL_UPLOAD_FAIL: J1.18, R20.2
SERIAL_UPLOAD_FAIL1: J5.18, R42.2
SERIAL_UPLOAD_FAIL2: J9.18, R64.2
SERIAL_UPLOAD_FAIL3: J13.18, R86.2
SERIAL_UPLOAD_FAIL4: J17.18, R108.2
SERIAL_UPLOAD_FAIL5: J21.18, R130.2
SERIAL_UPLOAD_PASS: J1.16, R19.2
SERIAL_UPLOAD_PASS1: J5.16, R41.2
SERIAL_UPLOAD_PASS2: J9.16, R63.2
SERIAL_UPLOAD_PASS3: J13.16, R85.2
SERIAL_UPLOAD_PASS4: J17.16, R107.2
SERIAL_UPLOAD_PASS5: J21.16, R129.2
SHUTDOWN: J1.29, R7.2, S1.1
SHUTDOWN1: J5.29, R29.2, S2.1
SHUTDOWN2: J9.29, R51.2, S3.1
SHUTDOWN3: J13.29, R73.2, S4.1
SHUTDOWN4: J17.29, R95.2, S5.1
SHUTDOWN5: J21.29, R117.2, S6.1
VCC_C: J3.6, J4.1
VCC_C1: J7.6, J8.1
VCC_C2: J11.6, J12.1
VCC_C3: J15.6, J16.1
VCC_C4: J19.6, J20.1
VCC_C5: J23.6, J24.1
VCC_T: J2.6, JP5.2
VCC_T1: J6.6, JP2.2
VCC_T2: J10.6, JP7.2
VCC_T3: J14.6, JP10.2
VCC_T4: J18.6, JP13.2
VCC_T5: J22.6, JP16.2
VCC_T_SELECTED: C4.1, C5.+, C7.1, JP1.1, JP3.1, JP5.1, R12.1, R14.1, R16.1, R18.1, R21.1, U2.14
VCC_T_SELECTED1: C12.1, C13.+, C14.1, JP2.1, JP4.1, JP6.1, R34.1, R36.1, R38.1, R40.1, R43.1, U4.14
VCC_T_SELECTED2: C19.1, C20.+, C21.1, JP7.1, JP8.1, JP9.1, R56.1, R58.1, R60.1, R62.1, R65.1, U6.14
VCC_T_SELECTED3: C26.1, C27.+, C28.1, JP10.1, JP11.1, JP12.1, R78.1, R80.1, R82.1, R84.1, R87.1, U8.14
VCC_T_SELECTED4: C33.1, C34.+, C35.1, JP13.1, JP14.1, JP15.1, R100.1, R102.1, R104.1, R106.1, R109.1, U10.14
VCC_T_SELECTED5: C40.1, C41.+, C42.1, JP16.1, JP17.1, JP18.1, R122.1, R124.1, R126.1, R128.1, R131.1, U12.14

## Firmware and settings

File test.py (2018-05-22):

# Raspberry Pi stand alone AVR programmer
# SparkFun Electronics
# Pete Lewis 7/1/2016
# More about Avrdude install/setup/use can be found at
# https://learn.adafruit.com/program-an-avr-or-arduino-using-raspberry-pi-gpio-pins/

# This python script bassically does this:
# Press a button to engage programming
# Programming BASH file is called pi_program.sh
# This contains all the calls to avrdude, including firmware, fuses and other flags
# Indicate status on a few LEDs - ideally we can show success at fuse bits, program, and lock bits.

import os, sys
import shutil
import serial
import time
import RPi.GPIO as GPIO
import filecmp

STAT = 7
FUSE_P = 15
FUSE_F = 13
FLASH_P = 31
FLASH_F = 11
LOCK_P = 32
LOCK_F = 22
SERIAL_P = 16
SERIAL_F = 18
PGM_SWITCH = 36

CAPSENSE = 33
SHUTDOWN = 29

STATLED_ON = False # Used for toggling stat led on and off during main loop

GPIO.setwarnings(False)
GPIO.setmode(GPIO.BOARD)

GPIO.setup(STAT, GPIO.OUT)
GPIO.setup(FUSE_P, GPIO.OUT)
GPIO.setup(FUSE_F, GPIO.OUT)
GPIO.setup(FLASH_P, GPIO.OUT)
GPIO.setup(FLASH_F, GPIO.OUT)
GPIO.setup(LOCK_P, GPIO.OUT)
GPIO.setup(LOCK_F, GPIO.OUT)
GPIO.setup(SERIAL_P, GPIO.OUT)
GPIO.setup(SERIAL_F, GPIO.OUT)
GPIO.setup(PGM_SWITCH, GPIO.OUT)

GPIO.setup(SHUTDOWN, GPIO.IN, pull_up_down=GPIO.PUD_UP) # with internal pullup enabled - trying this out to avoid accidental shutdowns.
#GPIO.setup(SHUTDOWN, GPIO.IN) # NO INTERNAL PULLUP
GPIO.setup(CAPSENSE, GPIO.IN)

GPIO.output(STAT, GPIO.LOW)
GPIO.output(FUSE_P, GPIO.LOW)
GPIO.output(FUSE_F, GPIO.LOW)
GPIO.output(FLASH_P, GPIO.LOW)
GPIO.output(FLASH_F, GPIO.LOW)
GPIO.output(LOCK_P, GPIO.LOW)
GPIO.output(LOCK_F, GPIO.LOW)
GPIO.output(SERIAL_P, GPIO.LOW)
GPIO.output(SERIAL_F, GPIO.LOW)
GPIO.output(PGM_SWITCH, GPIO.LOW) # LOW is OFF, this is active high, hardware has 10K pullup

firmware_path_media = ' '
new_hex = False
copy_flag = False

bash_path_media = ' '
new_bash = False
copy_flag_bash = False

test_dot_py_path_media = ' '
new_test_dot_py = False
copy_flag_test_dot_py = False

stat_blink_counter = 0

LOCK_BITS_PASS = False #Used to know if lock bits programming passed or failed, and then determine if we should even both carrying on with Serial upload attempts

def all_leds_on():
        GPIO.output(STAT, GPIO.HIGH)
        GPIO.output(FUSE_P, GPIO.HIGH)
        GPIO.output(FUSE_F, GPIO.HIGH)
        GPIO.output(FLASH_P, GPIO.HIGH)
        GPIO.output(FLASH_F, GPIO.HIGH)
        GPIO.output(LOCK_P, GPIO.HIGH)
        GPIO.output(LOCK_F, GPIO.HIGH)
        GPIO.output(SERIAL_P, GPIO.HIGH)
        GPIO.output(SERIAL_F, GPIO.HIGH)

def all_leds_off():
        GPIO.output(STAT, GPIO.LOW)
        GPIO.output(FUSE_P, GPIO.LOW)
        GPIO.output(FUSE_F, GPIO.LOW)
        GPIO.output(FLASH_P, GPIO.LOW)
        GPIO.output(FLASH_F, GPIO.LOW)
        GPIO.output(LOCK_P, GPIO.LOW)
        GPIO.output(LOCK_F, GPIO.LOW)
        GPIO.output(SERIAL_P, GPIO.LOW)
        GPIO.output(SERIAL_F, GPIO.LOW)

def blink_circle():
        GPIO.output(FUSE_P, GPIO.HIGH)
        time.sleep(.1)
        GPIO.output(FUSE_P, GPIO.LOW)
        GPIO.output(FLASH_P, GPIO.HIGH)
        time.sleep(.1)
        GPIO.output(FLASH_P, GPIO.LOW)
        GPIO.output(LOCK_P, GPIO.HIGH)
        time.sleep(.1)
        GPIO.output(LOCK_P, GPIO.LOW)
        GPIO.output(LOCK_F, GPIO.HIGH)
        time.sleep(.1)
        GPIO.output(LOCK_F, GPIO.LOW)
        GPIO.output(FLASH_F, GPIO.HIGH)
        time.sleep(.1)
        GPIO.output(FLASH_F, GPIO.LOW)        
        GPIO.output(FUSE_F, GPIO.HIGH)
        time.sleep(.1)
        GPIO.output(FUSE_F, GPIO.LOW)

def relaunch_python():
        command = "sh /home/pi/relaunch_python.sh"
        import subprocess
        process = subprocess.Popen(command.split(), stdout=subprocess.PIPE)
        output = process.communicate()[0]
        print output     
        
def update_firmware_and_bash_and_test_dot_py():
        global new_hex
        new_hex = False
        global firmware_path_media
        global copy_flag
        
        global new_bash
        new_bash = False
        global bash_path_media
        global copy_flag_bash
        
        global new_test_dot_py
        new_test_dot_py = False
        global test_dot_py_path_media
        global copy_flag_test_dot_py  
        
        for root, dirs, files in os.walk('/media'):
                for name in files:
                        #print (os.path.join(root, name))
                        tempstring = (os.path.join(root, name))
                        if 'hex' in tempstring and 'SERIAL_UPLOAD' not in tempstring:
                                #print 'new hex file found!!'
                                new_hex = True
                                #print tempstring
                                firmware_path_media = tempstring
                        if 'pi_program.sh' in tempstring:
                                #print 'new bash file found!!'
                                new_bash = True
                                #print tempstring
                                bash_path_media = tempstring
                        if 'test.py' in tempstring:
                                #print 'new test.py file found!!'
                                if(filecmp.cmp(tempstring, '/home/pi/test.py') == False):
                                               new_test_dot_py = True
                                #print tempstring
                                test_dot_py_path_media = tempstring                                  
        if(new_hex == False):
                #print 'no new hex'
                copy_flag = False
        elif((new_hex == True) and (copy_flag == False)):
                blink_circle()
                print 'new hex found'
                print firmware_path_media
                # first, delete the old hex file
                for root, dirs, files in os.walk('/home/pi'):
                        for name in files:
                                #print (os.path.join(root, name))
                                old_firmware_path = (os.path.join(root, name))
                                if 'hex' in old_firmware_path and 'SERIAL_UPLOAD' not in old_firmware_path:
                                        print 'old hex file found!!'
                                        print 'deleting old firmware file:'
                                        print old_firmware_path
                                        os.remove(old_firmware_path)
                                        print 'done'
                copy_flag = True # to avoid copying the file EVERY loop, we only need to do it once
                print 'copying hex file to local folder /home/pi'
                shutil.copy(firmware_path_media, '/home/pi')
                print 'done'
        if(new_bash == False):
                #print 'no new bash'
                copy_flag_bash = False
        elif((new_bash == True) and (copy_flag_bash == False)):
                blink_circle()
                print 'new bash found'
                print bash_path_media
                # first, delete the old bash file
                print 'deleting old bash file: /home/pi/pi_program.sh'
                os.remove('/home/pi/pi_program.sh')
                print 'done'            
                copy_flag_bash = True # to avoid copying the file EVERY loop, we only need to do it once
                print 'copying bash file to local folder /home/pi'
                shutil.copy(bash_path_media, '/home/pi')
                print 'done'
        if(new_test_dot_py == False):
                #print 'no new bash'
                copy_flag_test_dot_py = False
        elif((new_test_dot_py == True) and (copy_flag_test_dot_py == False)):
                blink_circle()
                print 'new test.py found'
                print test_dot_py_path_media
                # first, delete the old bash file
                print 'deleting old test.py file: /home/pi/test.py'
                os.remove('/home/pi/test.py')
                print 'done'            
                copy_flag_test_dot_py = True # to avoid copying the file EVERY loop, we only need to do it once
                print 'copying test.py file to local folder /home/pi'
                shutil.copy(test_dot_py_path_media, '/home/pi')
                print 'done'
                relaunch_python()
                
def shut_down():
        print "shutting down"
        command = "/usr/bin/sudo /sbin/shutdown -h now"
        import subprocess
        process = subprocess.Popen(command.split(), stdout=subprocess.PIPE)
        output = process.communicate()[0]
        print output
        
def clean_results():
        f = open('/home/pi/fuse_results.txt', 'w')
        f.truncate()
        f.close()
        f = open('/home/pi/flash_results.txt', 'w')
        f.truncate()
        f.close()
        if (os.path.exists('/home/pi/SERIAL_UPLOAD/pi_serial_upload.sh') == True):
                f = open('/home/pi/SERIAL_UPLOAD/serial_upload_results.txt', 'w')
                f.truncate()
                f.close()
                f = open('/home/pi/SERIAL_UPLOAD/serial_upload_results_temp.txt', 'w')
                f.truncate()
                f.close()        
        
def program():
        #GPIO.setup(PGM_SWITCH, GPIO.IN)
	GPIO.output(PGM_SWITCH, GPIO.HIGH)
	time.sleep(.1)        
        clean_results()
        #command = "/usr/bin/sudo ./pi_program.sh"
        #command = "sudo ./pi_program.sh"
        command = "sh /home/pi/pi_program.sh"
        #command = "/usr/bin/sudo avrdude -p atmega328p -C /home/pi/avrdude_gpio.conf -c pi_1 -D -e 2>output1.txt"
        #command = "/usr/bin/sudo dir"
        import subprocess
        process = subprocess.Popen(command.split(), stdout=subprocess.PIPE)
        output = process.communicate()[0]
        print output
        print "...programming done."
        #GPIO.setup(PGM_SWITCH, GPIO.OUT)
	GPIO.output(PGM_SWITCH, GPIO.LOW) # LOW is OFF, this is active high, hardware has 10K pullup
        

def killall_avrdude():
        command = "sudo killall avrdude"
        import subprocess
        process = subprocess.Popen(command.split(), stdout=subprocess.PIPE)
        output = process.communicate()[0]
        print output
        print "...killing all avrdude."	

def program_serial():
        serial_hopeful = False
        print "serial programming beginning..."
        #command = "bash /home/pi/SERIAL_UPLOAD/pi_serial_upload.sh" #Use BASH for more funcitonality (if coniditionsals etc), but be warned this can add 4-5 seconds before the command begins running
        command = "sh /home/pi/SERIAL_UPLOAD/pi_serial_upload.sh" # default to "SH" for immediately running command - useful to still work with serial timeout failure feature
        import subprocess
        process = subprocess.Popen(command.split(), stdout=subprocess.PIPE)
        #output = process.communicate()[0]
        #print output
        time.sleep(1.5) # WAIT for serial upload to either show successful ping to target (or to not, and indicate that this isn't very hopeful)
        shutil.copy('/home/pi/SERIAL_UPLOAD/serial_upload_results.txt', '/home/pi/SERIAL_UPLOAD/serial_upload_results_temp.txt')
        f_temp = open('/home/pi/SERIAL_UPLOAD/serial_upload_results_temp.txt', 'r')
        for line in f_temp:
                if 'avrdude: AVR device initialized and ready to accept instructions' in line:
                        serial_hopeful = True
                        print "Serial Upload in progress and looking hopeful :)"
                        output = process.communicate()[0] #This basically makes us what until the communication from the programming subprocess is done
                        print "serial upload done."
        if (serial_hopeful == False):
                process.terminate()
		killall_avrdude()
                print "Serial Upload failure... killing subprocess and moving on"
                        

def parse_results():
        #variables to store success/failure of each programming step
        hfuse = False
        lfuse = False
        efuse = False
        flash = False
        lock = False
        global LOCK_BITS_PASS
        LOCK_BITS_PASS = False
        hash_verified_count = 0 # need to see 3 of these lines in the programming readout when programming an ESP32 chip
        f = open('/home/pi/fuse_results.txt', 'r')
        for line in f:
                if 'avrdude: 1 bytes of hfuse verified' in line:
                        print line
                        hfuse = True
                elif 'avrdude: 1 bytes of lfuse verified' in line:
                        print line
                        lfuse = True
                elif 'avrdude: 1 bytes of efuse verified' in line:
                        print line
                        efuse = True
                elif 'avrdude: AVR device not responding' in line:
                        print line
        f.close()

        f = open('/home/pi/flash_results.txt', 'r')
        FLASH_SIZE = '00000'    # the flash size can vary slightly depending on the hex file (I think)
                                # I've seen 32652, 32768, and 32650 in the three examples I've tried,
                                # So pulling in this variable became necessary to use in verifying the correct message
                                # when parsing flash_results.txt
        for line in f:
                if 'avrdude: writing flash (' in line:  # This is the line that contains the flash file size
                                                        # The complete line looks like this:
                                                        # "avrdude: writing flash (32670 bytes):"
                        FLASH_SIZE = line[24:(line.find('byte')-1)]
                        print 'FLASH_SIZE:' + FLASH_SIZE
                elif 'avrdude: ' + FLASH_SIZE + ' bytes of flash verified' in line: # Look for complete verification line
                        print line
                        flash = True                       
                elif 'avrdude: 1 bytes of lock verified' in line:
                        print line
                        lock = True
                        LOCK_BITS_PASS = True
                elif 'avrdude: AVR device not responding' in line:
                        print line
                elif 'Hash of data verified.' in line:
                        hash_verified_count += 1
                        print line
        f.close()        

        ## display results on all 6 stat LEDs
        if(hash_verified_count == 3): # this means we are programming an ESP32, and only care to light up the flash_P led.
                GPIO.output(FLASH_P, GPIO.HIGH)
        else: # everything not an ESP32 - ATmega328 and mega2560 supported
                if((hfuse == True) and (lfuse == True) and (efuse == True)):
                        GPIO.output(FUSE_P, GPIO.HIGH)
                else:
                        GPIO.output(FUSE_F, GPIO.HIGH)
                if(flash == True):
                        GPIO.output(FLASH_P, GPIO.HIGH)
                else:
                        GPIO.output(FLASH_F, GPIO.HIGH)
                if(lock == True):
                        GPIO.output(LOCK_P, GPIO.HIGH)
                else:
                        GPIO.output(LOCK_F, GPIO.HIGH)

def parse_results_serial():
        #variables to store success/failure of serial flash writing
        # NOTE, I am NOT verifying flash on serial upload to decrease programming time by 50%
        # So we are going to show a successful serail program, but only seeing that it was written
        serial_flash_written = False

        f = open('/home/pi/SERIAL_UPLOAD/serial_upload_results.txt', 'r')
        FLASH_SIZE = '00000'    # the flash size can vary

        for line in f:
                if 'avrdude: writing flash (' in line:  # This is the line that contains the flash file size
                                                        # The complete line looks like this:
                                                        # "avrdude: writing flash (32670 bytes):"
                        FLASH_SIZE = line[24:(line.find('byte')-1)]
                        print 'FLASH_SIZE:' + FLASH_SIZE
                elif 'avrdude: ' + FLASH_SIZE + ' bytes of flash written' in line: # Look for complete line 
                        print line
                        serial_flash_written = True                       
                elif 'avrdude: AVR device not responding' in line:
                        print line
        f.close()        

        ## display results on serial upload LEDs

        if(serial_flash_written == True):
            GPIO.output(SERIAL_P, GPIO.HIGH)
            print 'Serial Write success!!'
        else:
            GPIO.output(SERIAL_F, GPIO.HIGH)                               
        
def toggle_stat_led():
        global STATLED_ON
        if (STATLED_ON):
                GPIO.output(STAT, GPIO.LOW)
                STATLED_ON = False
        else:
                GPIO.output(STAT, GPIO.HIGH)
                STATLED_ON = True

def blink_all():
        all_leds_on()
        time.sleep(.1)
        all_leds_off()

time.sleep(3) # let 3.3V line settle to avoid accidental shutdowns
while True:
        time.sleep(.1)
        stat_blink_counter += 1
        if(stat_blink_counter > 5):
                toggle_stat_led()
                stat_blink_counter = 0
        
        update_firmware_and_bash_and_test_dot_py()
        #print GPIO.input(SHUTDOWN)
        
        if GPIO.input(SHUTDOWN) == False:
                counter = 0
                while GPIO.input(SHUTDOWN) == False:
                        counter += 1
                        print counter
                        blink_all()
                        time.sleep(.5)
                        if counter > 4:
                                all_leds_on()
                                shut_down()

        if GPIO.input(CAPSENSE) == True:
                blink_all()
                GPIO.output(STAT, GPIO.HIGH) #indicate programming attempt
                program()
                parse_results()
                if ((os.path.exists('/home/pi/SERIAL_UPLOAD/pi_serial_upload.sh') == True) and (LOCK_BITS_PASS == True)):
                        # time.sleep(1) # Delay to allow com port enumeration.
                        # Note, this delay is only needed with micros that have USB capabilities (like the atmega32u4)
                        program_serial()
                        parse_results_serial()
                        time.sleep(3) # led leds stay on for 3 secs
                else:
                        time.sleep(3) # led leds stay on for 3 secs
                all_leds_off()

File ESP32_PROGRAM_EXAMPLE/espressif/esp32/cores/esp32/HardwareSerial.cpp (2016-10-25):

#include <stdlib.h>
#include <stdio.h>
#include <string.h>
#include <inttypes.h>

#include "HardwareSerial.h"

HardwareSerial Serial(0);

HardwareSerial::HardwareSerial(int uart_nr) : _uart_nr(uart_nr), _uart(NULL) {}

void HardwareSerial::begin(unsigned long baud, uint32_t config, int8_t rxPin, int8_t txPin)
{
    if(_uart_nr == 0 && rxPin < 0 && txPin < 0) {
        rxPin = 3;
        txPin = 1;
    }
    _uart = uartBegin(_uart_nr, baud, config, rxPin, txPin, 256, false);
}

void HardwareSerial::end()
{
    if(uartGetDebug() == _uart_nr) {
        uartSetDebug(0);
    }
    uartEnd(_uart);
    _uart = 0;
}

void HardwareSerial::setDebugOutput(bool en)
{
    if(_uart == 0) {
        return;
    }
    if(en) {
        uartSetDebug(_uart);
    } else {
        if(uartGetDebug() == _uart_nr) {
            uartSetDebug(0);
        }
    }
}

int HardwareSerial::available(void)
{
    return uartAvailable(_uart);
}

int HardwareSerial::peek(void)
{
    if (available()) {
        return uartPeek(_uart);
    }
    return -1;
}

int HardwareSerial::read(void)
{
    if(available()) {
        return uartRead(_uart);
    }
    return -1;
}

void HardwareSerial::flush()
{
    uartFlush(_uart);
}

size_t HardwareSerial::write(uint8_t c)
{
    uartWrite(_uart, c);
    return 1;
}

size_t HardwareSerial::write(const uint8_t *buffer, size_t size)
{
    uartWriteBuf(_uart, buffer, size);
    return size;
}

HardwareSerial::operator bool() const
{
    return _uart != 0;
}

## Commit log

2016-07-06 initial commit, hardware still needs routing
    includes some of the necessary files that go onto the Raspberry Pi.
    [Pigrammer.brd, Pigrammer.sch]
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2016-07-06 Moved ISP 3x2 header to right side
    I had to move header to avoid the bottom side of the pins hitting the
    enclosure. The PCB is designed to sit flush on top of the raspi
    enclosure.
    [Pi_grammer.brd]
2016-07-06 added silk labeling to isp header pins
    [Pi_grammer.brd]
2016-07-06 routed
    also added .job and .pro to gitignore - eagle auto routing files
    [Pi_grammer.brd]
2016-07-08 Corrected capsense pad to be on top layer
    whoops
    [Pi_grammer.brd, Pi_grammer.sch]
2016-07-08 updating to work with new shield hardware
    updated GPIO assignment for all LEDs.
    removed old LED assignments and related function calls
    created all_leds_off() funtion for use during programming cycle
    updated "main" while loop at the end to also watch the capsense net, and
    engage programming. Tweeked the counter amounts for snappy response.
    Added LED control to end of parse_results() function, to indicate
    statuses via LEDs. Kept debug printing for use with python terminal
    open.
    [test.py]
2016-07-13 Moved ICSP lines to a 1x6 connector
    Also created adapter from 1x6 cable to 3x2 header
    [Pi_grammer.brd, Pi_grammer.sch]
2016-07-13 changes "script running" led silk to "STAT"
    [Pi_grammer.brd]
2016-08-05 complete paths, clean results, added "sh" to command
    the "sh" prior to the command sends any readout from prompt to the tty1
    - which I learned you can view by pressing crtl alt F1. Note Crtl Alt F7
    will talk you back to the desktop.
    Added blink cirle to indicate firmware update
    added delete old firmware files beofre the copy from media happens
    Made the repsonse a bit more snappy with the new stat counter, and made
    it react immediately on the first instance of a putton press.
    [test.py]
2016-08-15 Auto-updating of bash file now included
    update_firmware_and_bash() not includes a search on any attached media
    device to look for "pi_program.sh" file. If present, it will copy it
    over to "/home/pi" folder.
    Also changed the blink_cirlce indication to a single blink circle per
    update, so you should see a single circle blink for firmware update, and
    another circle for bash file update.
    This will be useful if you need to adjust anything in the bash. When
    creating a Pi_grammer from scratch, you should be able to just throw the
    correct firmware and a complete bash file onto a thumb drive and pop it
    into the pi_grammer, and wallah, you've got your stand alone programmer
    setup.
    [test.py]
2016-08-16 PROD_IDs to all populated parts, SCH cleanup
    [Pi_grammer.brd, Pi_grammer.sch]
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2016-08-22 Changed value of R7 to 1K
    This is the pullup resistor on the SHUTDOWN line/button. I was seeing
    some strange behavior on a few shields that would actually cause a
    shutdown right at bootup. Getting a little more current on this pullup
    seems to have solved the issue.
    [Pi_grammer.brd, Pi_grammer.sch]
2016-08-25 Split design into MAIN and ADAPTER
    The original eagle file contained both PCBs for this project. As
    requested by production, I split them out into separate design files -
    for ease of CAMing and ordering.
    [Pi_grammer_ADAPTER.brd, Pi_grammer_ADAPTER.sch, Pi_grammer_MAIN.brd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]
2016-08-25 Moved into separate folders
    [Pi_grammer_ADAPTER.brd, Pi_grammer_ADAPTER.sch, Pi_grammer_MAIN.brd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]
2016-09-02 Flash size now finds with larger files
    When programming a mega, the flash size can contain one more character,
    so I had to use line.find tool to get the trimming of the line correct.
    [test.py]
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2016-09-12 Serial Upload to reference on MAIN board.
    Planning ot make a little "add on" board to drop on top of the MAIN
    board. It will provide serial upload success/fail LEDs off of GPIO 20
    and 21. The idea is to have castellated edge PTH pins to connect to the
    bottom 4 pins of the 2x20 connector. We really only need GND and the two
    GPs, but I figured 4 will provide better stability.
    [Pi_grammer_MAIN.brd]
2016-09-12 Added serial upload add on board
    Left a lot of stuff on reference, for reference.
    [Pi_grammer_SERIAL_UPLOAD_ADD_ON.brd, Pi_grammer_SERIAL_UPLOAD_ADD_ON.sch]
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2017-04-18 adding in support for linuxspi
    need this as an option in the config file.
    NOTE RESET IS ON GPIO PIN 25 - this may need to change
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2017-04-18 GPIO 26 is better for RESET on linuxspi
    it's a good location for hand soldering an adapter to it, also it
    doesn't conflict with lock bits fail LED (currently on GPIO25)
2017-04-19 hard reset via direct gpio control
    I was seeing strange behavior with fresh boards on the microview ganged
    programmer. It would successfully program fuses, but then always fail to
    enter programming mode for the flash programming step. It worked fine if
    you tried once, reset power to boards, then programmed a second time.
    Also, note it was working fine with first time programming on fresh ICs
    with the older GPIO bit banging programmer method (although really
    slow). I thought it might be just the way that the linuxspi was
    resetting... still not entirely sure. But a hard reset via direct gpio
    control works every time.
    Also note, you need to install wiringPI for the command lines to work.
    see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
2017-04-25 ADD ON boards for SPI logic level conversion
    The bi-directional logic level converter has been working in my testing.
    I have yet to get the TXB0104 chip to work, so I just want to try it
    out. (supposedly it will work better).
    Also, created a mini library with the special raspi header - for top
    mounting - it has larger drills and annular rings to fit on top of a
    populated header with fillets.
    [Pi_grammer_SPEEDY_SPI.brd, Pi_grammer_SPEEDY_SPI.sch, Pi_grammer_SPEEDY_SPI_V2.brd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]
2017-04-27 SPEED SPI layout work
    locking footprint on converter.
    moved to 16 mils traces everywhere.
    curved traces to keep length of data lines as similar as possible.
    removed pin 20 GND on PI header. Not necessary and wanted more clearance
    from nearby data trace.
    [Pi_grammer_SPEEDY_SPI_V2.brd, Pi_grammer_SPEEDY_SPI_V2.sch]
2017-04-27 reorganizing folders for SPEEDY SPI versions V1 and V2
    I want to keep the TXB layout around, maybe even try it out, but I know
    V2 should work (cause I got it to work actually using the BOB and wiring
    it up.
    [Pi_grammer_SPEEDY_SPI_V1.brd, Pi_grammer_SPEEDY_SPI_V1.sch, Pi_grammer_SPEEDY_SPI_V2.brd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]
2017-04-27 Option to "tap" logic level from target
    Note, this required a modification to the ADAPTER as well. I am
    utilizing pin 6 on the 1x6 pin header (jumper wire) to transfer VCC back
    to the logic level converter.
    I'm not sure why on the original design I didn't think to include VCC in
    the comm lines to the target - I think it was because the raspi doesn't
    have any ADCs to actually verify it, so I didn't know if it was worth
    it.
    [Pi_grammer_ADAPTER.brd, Pi_grammer_ADAPTER.sch, Pi_grammer_SPEEDY_SPI_V2.brd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]
2017-04-28 Speedy SPI library work
    updated device to only include pins/pads that are used. added in actual
    drill hits for the unused pads.
    rduced down to only 2 GND connections.
    reduce isolate to 10 mils to allow for GND flow across header pins.
    [Pi_grammer_SPEEDY_SPI_V2.brd, Pi_grammer_SPEEDY_SPI_V2.sch]
2017-04-28 moved 1x6 header to allow for RA header
    This should allow for the cable to flow directly downward from the
    pi_grammer and sit with a lower profile. This should help prevent the
    cable/header from getting knocked around during handling.
    Also had to update the adapter - rotated header 180 degrees so it will
    mate straight pin-to-pin on the 1x6 header on the speedySPI.
    [Pi_grammer_ADAPTER.brd, Pi_grammer_SPEEDY_SPI_V2.brd, Pi_grammer_SPEEDY_SPI_V2.sch]
2017-05-26 Speedy SPI corrections
    Extended out to the right, and scooted all components to clear current
    Pi_grammer "hat" design.
    On V2, I had to solder all of the PTH pins flush on the bottom, and the
    SMD parts below the LLC get in the way.
    [Pi_grammer_SPEEDY_SPI_V3.brd, Pi_grammer_SPEEDY_SPI_V3.sch]
2017-06-20 SPI pins and llc
    Just SCH work at this point.
    [Pi_grammer_MAIN.brd, Pi_grammer_MAIN.sch]
2017-06-20 Initial part placement
    still need to possibly swap out the capsense IC, so not gonna route
    anything yet.
    ALSO - the serial upload pins need to be connected to GPIO - need to
    verify which pins can drive LEDs.
    [Pi_grammer_MAIN.brd]
2017-06-28 capsense IC replacement
    trying out the UDFN package - dang that's tiny
    [Pi_grammer_MAIN.brd, Pi_grammer_MAIN.sch]
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2017-06-28 updated SFE flame to proper polygon width dran package
    [Pi_grammer_MAIN.brd, Pi_grammer_MAIN.sch]
2017-07-14 Serial upload working for RedBoards
    Note, I had to install arduino onto the Pi. And then I just watched
    verbose debug while using the IDE and copied the avrdude calls. See
    /SERIAL_UPLOAD/readme.txt for more info.
    Also adjusted/added to the test.py module. It now has a proper
    parse_results_serial() function to verify that the target was written to
    (although I omitted actual hex read-back verification to save time).
    Also, There is support for Serial upload pass/fail LEDs, however I have
    not yet tried this with hardware... just getting ready for when
    Pi_grammer v2.0 is built up.
    [test.py]
2017-08-16 BOM update - library and PROD_ID stuff
    No change to design, just did a replace to correct parts in library.
    Note, I also had to manually adjust the PROD_ID for the RA header,
    because I didn't want to muddy up the device for this part.
    [Pi_grammer_MAIN.brd, Pi_grammer_MAIN.sch]
2017-11-17 Serial upload stuff
    Added in LOCK_BITS_PASS variable so that I can avoid attempting a serial
    upload if there is any failures upstream.
    Also, started checking a "temp" copy of readout from serial program, to
    adetify if it's looking hopeful. If it's going to fail, then it usually
    takes about 30 seconds to timeout, and can appear to the tech that the
    pi_grammer has frozen. This helps avoid this illusion.
    Also, this is still not killing the subprocess, and I'm not sure how to
    do that properly. So even though I move on in the python module, the
    serial upload bash file is still going and timeing out again and again
    until it's totally done in about 30 seconds.
    [test.py]
2017-12-14 fixing clean_results bug
    If you are not using the SERIAL_UPLOAD feature, it will no longer try to clean up that file.
    Note, previously, it would try to truncate a file that doesn't exist and lock up the program :(
    fixed now!!
    [test.py]
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2017-12-22 Pi_grammer ADD-ON board to isolate programmer from target
    My idea here is to be able to swtich the lines to completely disconnect the pi_grammer from the target.
    *This stemmed from a programming procedure on the lilypad MP3 where the SPI lines are used by the product's ATmega328 to take to the uSD card, so the pi_grammer is stopping that. I hope to free up th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
    [Pi_grammer_SPI_ISOLATE.brd, Pi_grammer_SPI_ISOLATE.sch]
2017-12-28 Re-creating pi_program on Raspi to avoid strange CR behavior
    Note, I was seeing some errors being thrown in the raspi when I tried to run pi_program.sh - it was showing that the command "sleep 0.1\r" was an invalid value for sleep. I'm assuming that the "\r" is some annoying carrage return from editing the file on a windows machine.
    Added comments around the device variable
2018-01-19 on serial upload failure - added killall avrdude
    When serial upload fails, it will take FOREVER for avrdude to attempt (like 10 times) to serial upload, and it will timeout on each of those attempts. Rather than waiting for that to finish (which looks like the pi is frozen to the user), I take a snapshot of the results and parse them a bit. I can tell that it's going south, and then kill it. Previously the "process.terminate()" wasn't working - and I think it still doesn't do much. But the call to "sudo killall avrdude" really does the trick.
    Also note, in the previous test.py, even though the python module would move on, the avrdude instance would continue. This would lock up the com port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
    [test.py]
2018-01-22 Increased Serial upload "timeout" time to 1.5 seconds
    I found while deving the FJ, that sometimes the serial upload would need a bit more time to indicate success or failure. 1.5 seconds seems to do the trick.
    [test.py]
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2018-03-23 optional delay before serial program
    Note, this is commented out by default, but will be needed for doing any serial programming to micros that need a sec to enumerate the com port. See the following comment thread on the tutorial for more info about how the problem was discovered/fixed
    [https://learn.sparkfun.com/tutorials/raspberry-pi-stand-alone-programmer/discuss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](https://learn.sparkfun.com/tutorials/raspberry-pi-stand-alone-programmer/discuss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)
    [test.py]
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2018-03-29 pi_grammer v21
    Added in isolation switch
    [Pi_grammer_MAIN.brd, Pi_grammer_MAIN.sch]
2018-03-29 deleting old ADD ON boards
    These are now baked into the MAIN board v21
    [Pi_grammer_SERIAL_UPLOAD_ADD_ON.brd, Pi_grammer_SERIAL_UPLOAD_ADD_ON.sch, Pi_grammer_SPEEDY_SPI_V1.brd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]
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2018-04-20 Swapped out package to paste-closed jumper for TARGET VCC
    This needed a default target logic select. It is now closed (selected) via paste on the "TARGET VCC" option.
    [Pi_grammer_MAIN.brd, Pi_grammer_MAIN.sch]
2018-04-24 Adapter updates for storefront product
    -Added open source hardware logo
    -sparkfun flame
    -"product" board name
    -schematic cleanup
    -removed rounded cornders for easier board de-panelization
    -lengthened board to eliiminate overhaning parts
    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
    [Pi_grammer_ADAPTER.brd, Pi_grammer_ADAPTER.sch]
2018-04-24 correcting adapter name to "AVR_ADAPTER"
    [Pi_grammer_AVR_ADAPTER.brd, Pi_grammer_AVR_ADAPTER.sch]
2018-04-24 pi_grammer_MAIN updates for storefront product
    -moved to RA SMT 1x6 header for programming lines to cable, had to re-route a few things, MISO and MOSI have a much better direct route now.
    -Enlarged most silk to standard 0.05
    -changed text silk on "blank boxes" to more generic use case terms - project name, version, date etc.
    -added prod ID to switch IC
    -updated copper and sch version number to v22
    -added large sparkfun logo to bottom side silk
    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
    [Pi_grammer_MAIN.brd, Pi_grammer_MAIN.sch]
2018-04-25 updated AT42QT1010 to pull from the proper sparkfun eagle sensor library dev
    [Pi_grammer_MAIN.brd, Pi_grammer_MAIN.sch]
2018-04-25 updated switch (U2) to use sparkfun eagle library
    also updated all libraries and the LEDs silk changed to updated versions of 1206 packages
    [Pi_grammer_MAIN.brd, Pi_grammer_MAIN.sch]
2018-04-25 RA SMD 6 pin header updated to have correct prod ID
    [Pi_grammer_MAIN.brd, Pi_grammer_MAIN.sch]
2018-04-25 schematic frame update to CC 4.0
    [Pi_grammer_MAIN.brd, Pi_grammer_MAIN.sch]
2018-04-25 schematic cleanup and notes
    [Pi_grammer_MAIN.brd, Pi_grammer_MAIN.sch]
2018-04-25 prod_ID correction on at42QT1010
    manually adjusted from the old package part in sparkle to the new UDFN
    [Pi_grammer_MAIN.brd, Pi_grammer_MAIN.sch]
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2018-04-30 Changed a 3.3V net flag to a proper "VCC" symbol
    Note, this flag was for the 3.3V hitting the resistor for the "POWER" LED.
    [Pi_grammer_MAIN.brd, Pi_grammer_MAIN.sch]
2018-05-21 re-naming a lot to correct product name "SparkFun_Pi_AVR_Programmer_HAT"
    [13490-Pi_grammer_MAIN-panel.v10.brd, SparkFun_Pi_AVR_Programmer_ADAPTER.brd, SparkFun_Pi_AVR_Programmer_ADAPTER.sch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]
2018-05-21 Adjusted silk for new product name
    Also updated all silk to sweet buzzard style labels
    [SparkFun_Pi_AVR_Programmer_ADAPTER.brd, SparkFun_Pi_AVR_Programmer_HAT.brd, SparkFun_Pi_AVR_Programmer_HAT.sch]
2018-05-22 reverting to default "SH" in serial upload shell call
    Note, I kept "BASH" option commented out to have nearby for reference with comments.
    [test.py]
2018-05-29 fixed hatch ground pour under capsense pad
    Due to inverted sPlace (silk), it was hard to see that the hatched GND was actually gone. I must have ripped up a "floating" GND trace that connects the hatched GND polygon to the main GND polygon on the botton copper.
    [SparkFun_Pi_AVR_Programmer_HAT.brd]
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

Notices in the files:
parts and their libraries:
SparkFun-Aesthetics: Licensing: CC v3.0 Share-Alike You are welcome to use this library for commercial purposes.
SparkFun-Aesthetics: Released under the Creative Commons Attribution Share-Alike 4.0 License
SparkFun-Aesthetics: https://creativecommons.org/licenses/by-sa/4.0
